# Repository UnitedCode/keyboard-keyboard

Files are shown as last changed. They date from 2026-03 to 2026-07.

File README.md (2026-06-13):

# keyboard-keyboard

A hall-effect MIDI keyboard controller built around the Electrosmith Daisy Seed (STM32H750V). The layout follows the IBM Model M form factor but is tuned to work as a Wicki-Hayden isomorphic musical keyboard. Keys 81–100 are drum pads on MIDI channel 10.

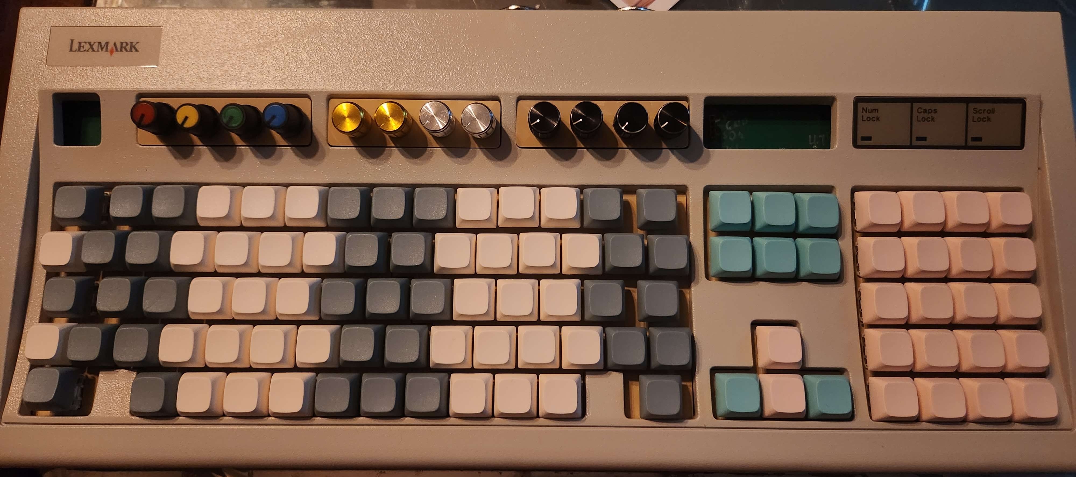
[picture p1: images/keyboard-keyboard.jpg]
keyboard-keyboard


## Hardware

- **MCU:** Electrosmith Daisy Seed Rev4 (STM32H750V)
- **Sensors:** 100x MT9105ET hall-effect sensors across 13 SN74LV4051A analog muxes (AM1–AM13)
- **Pots:** 12 trim potentiometers on AM14–AM15, read as MIDI CC
- **Display:** 128x32 SSD1306 OLED over I2C
- **MIDI:** USART1 at 31250 baud (DIN-5 out, opto-isolated in via 6N138)

The firmware currently drives 100 switches across all 13 muxes. AM10–AM13 require a hardware bodge to function — see [Known Issues](#known-issues).

Full pin mapping and mux architecture: [`keyboard_keyboard/code/HARDWARE.md`](keyboard_keyboard/code/HARDWARE.md)

KiCad schematic: `keyboard_keyboard/kicad/keyboard_keyboard.kicad_sch`

## Firmware

Firmware is in `keyboard_keyboard/code/`, written in Rust using [RTIC](https://rtic.rs/) for the real-time task scheduler.

### Setup

```sh
rustup target add thumbv7em-none-eabihf
rustup component add llvm-tools-preview
cargo install cargo-binutils
# probe-rs / cargo-embed: https://probe.rs/docs/getting-started/installation/
```

### Build and flash

Run these from `keyboard_keyboard/code/`:

```sh
cargo check        # type-check without a connected device
cargo build        # compile for thumbv7em-none-eabihf
cargo embed        # flash to Daisy Seed (reads Embed.toml)
```

RTT logs stream automatically during `cargo embed`. Set `DIAG_LOGGING = true` in `src/main.rs` for verbose per-switch ADC and baseline output.

GDB attach (in a separate terminal after `cargo embed`):

```sh
arm-none-eabi-gdb target/thumbv7em-none-eabihf/debug/app
# in gdb:
target remote :1337
```

### How it works

The `timer_handler` task fires at 1 kHz, scans all 13 muxes × 8 channels, and runs a three-state machine (`Idle → FirstActuated → FullyActuated`) per switch. Velocity is derived from the time between two ADC thresholds within an 80 ms window. Pot values are scanned every 10 ms and sent as CC messages. MIDI events queue into a `heapless::spsc::Queue` and are sent by a lower-priority `process_events` task.

Boot calibration averages 64 ADC samples per switch to establish per-key baselines before the timer starts.

## Known Issues

**U1 (74HC138D) PCB errata:** Pin 5 (`E2~`, active-low enable) is wired to +3.3V instead of GND, permanently disabling the decoder. AM10–AM13 (switches HE71–HE100) will not work until this is fixed.

Fix: solder bridge pin 5 → pin 4 (GND) on the SO16 package. They are adjacent.

**Daisy Seed errata:** Pad 33 (D26) has no ADC function. AM14/AM15 pot reads use A11 (D28, pad 35). Run a bodge wire from pad 33 → pad 35 and leave D26 unconfigured in firmware.

## Acknowledgements

- Hall-effect keyboard layout based on [peppapighs/HE60](https://github.com/peppapighs/HE60/tree/main)
- Model M physical layout based on [dcpedit/mod-mmm](https://github.com/dcpedit/mod-mmm)

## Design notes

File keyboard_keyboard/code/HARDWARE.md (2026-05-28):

# Hardware Reference — keyboard-keyboard

## Overview

Hall-effect MIDI keyboard controller on Electrosmith Daisy Seed (STM32H750V).
PCB hosts up to 15 analog muxes (AM1–AM15) feeding hall-effect sensors into Daisy ADC pins.
Firmware currently drives 9 muxes (70 keys, HE1–HE70). PCB supports 15 muxes, 100 hall-effect sensors (HE1–HE100).

KiCad schematic: `keyboard_keyboard/kicad/keyboard_keyboard.kicad_sch`

---

## Component Part Numbers

| Reference | Part Number | Description |
|---|---|---|
| A1 | Electrosmith Daisy Seed Rev4 | STM32H750V microcontroller module |
| AM1–AM15 | SN74LV4051APWR | 8-channel single-ended analog mux (TI, TSSOP-16) |
| HE1–HE100 | MT9105ET | Hall-effect sensor |
| U1 | 74HC138D | 3-to-8 line decoder / demultiplexer (NXP, SOIC-16) |
| U2 | 6N138 | Optocoupler — MIDI RX input isolation |

---

## Pin Mapping: Netlist → Daisy Seed

> **Important:** KiCad schematic uses physical pad numbers (1–40) matching Electrosmith pinout. Several pins labeled by STM32 alt-function (e.g., `DAC_OUT2`, `SAI2_MCLK`) are actually used as ADC inputs — Daisy exposes these as A7–A11.

| Netlist Pin | KiCad Pinfunction | Daisy Name | Role in Design |
|:---:|:---:|:---:|---|
| 2  | `SD_DATA_3`  | D1  | `led_3` |
| 3  | `SD_DATA_2`  | D2  | `ENB_C` → U1 decoder address A2 |
| 4  | `SD_DATA_1`  | D3  | `ENB_B` → U1 decoder address A1 |
| 5  | `SD_DATA_0`  | D4  | `ENB_A` → U1 decoder address A0 |
| 6  | `SD_CMD` | D5  | `led_2` |
| 7  | `SD_CLK` | D6  | `led_1` |
| 8  | `SPI1_CS` | D7  | MUX address A (`MUX_SELECT_0`) |
| 9  | `SPI1_SCK` | D8  | MUX address B (`MUX_SELECT_1`) |
| 10 | `SPI1_POCI`  | D9  | MUX address C (`MUX_SELECT_2`) |
| 12 | `I2C1_SCL` | D11 | I2C SCL → J3 |
| 13 | `I2C1_SDA` | D12 | I2C SDA → J3 |
| 14 | `USART1_TX`  | D13 | MIDI out (31250 baud) |
| 15 | `USART1_RX`  | D14 | MIDI in (31250 baud) |
| 22 | `ADC_0` | A0  | AM1 mux output |
| 23 | `ADC_1` | A1  | AM2 mux output |
| 24 | `ADC_2` | A2  | AM3 mux output |
| 25 | `ADC_3` | A3  | AM4 mux output |
| 26 | `ADC_4` | A4  | AM5 mux output |
| 27 | `ADC_5` | A5  | AM6 mux output |
| 28 | `ADC_6` | A6  | AM7 mux output |
| 29 | `DAC_OUT2` | A7  | AM8 mux output ← repurposed as ADC |
| 30 | `DAC_OUT1` | A8  | AM9 mux output ← repurposed as ADC |
| 31 | `SAI2_MCLK`  | A9  | AM10+AM11 shared ← repurposed as ADC |
| 32 | `SAI2_SD_B`  | A10 | AM12+AM13 shared ← repurposed as ADC |
| 33 | `SAI2_SD_A`  | A11 | AM14+AM15 shared ← repurposed as ADC |
| 16 | `AUDIO_IN_1` | — | Audio in 1 → J1 |
| 17 | `AUDIO_IN_2` | — | Audio in 2 → J1 |
| 18 | `AUDIO_OUT_1`| — | Audio out 1 → J2 |
| 19 | `AUDIO_OUT_2`| — | Audio out 2 → J2 |
| 36 | `USB_D_-` | D29 | USB D− → J6/J7 |
| 37 | `USB_D_+` | D30 | USB D+ → J6/J7 |
| 38 | `3V3_D` | — | 3.3V digital → all mux VDD |
| 39 | `VIN` | — | Power in → J6/J7 |
| 20 | `AGND` | — | Analog ground |
| 40 | `DGND` | — | Digital ground |

---

## Mux Architecture

### Address lines (shared by ALL 15 muxes)

| Signal | Daisy Pin | Selects |
|---|:---:|---|
| `MUX_SELECT_0` | D7 | A (bit 0) |
| `MUX_SELECT_1` | D8 | B (bit 1) |
| `MUX_SELECT_2` | D9 | C (bit 2) |

3 bits → 8 channels (X0–X7), selected simultaneously across all active muxes.

### Mux groups and ADC pins

AM1–AM9: dedicated ADC pin each. AM10–AM15: 3 pairs sharing an ADC pin — 74HC138 decoder (U1, driven by D2/D3/D4) enables one mux per pair at a time.

| ADC Pin | Daisy | Mux(es) | Notes |
|:---:|:-----:|---|---|
| ADC_0 | A0  | AM1 | dedicated |
| ADC_1 | A1  | AM2 | dedicated |
| ADC_2 | A2  | AM3 | dedicated |
| ADC_3 | A3  | AM4 | dedicated |
| ADC_4 | A4  | AM5 | dedicated |
| ADC_5 | A5  | AM6 | dedicated |
| ADC_6 | A6  | AM7 | dedicated |
| A7 | A7  | AM8 | dedicated (`DAC_OUT2` repurposed) |
| A8 | A8  | AM9 | dedicated (`DAC_OUT1` repurposed) |
| A9 | A9  | AM10, AM11 | pair — U1 enables one at a time |
| A10 | A10 | AM12, AM13 | pair — U1 enables one at a time |
| A11 | A11 | AM14, AM15 | pair — U1 enables one at a time |

### U1 — 74HC138 decoder (mux pair enables)

Driven by D2 (A2), D3 (A1), D4 (A0). Outputs active-low `ENABLE_10`–`ENABLE_15`, controlling which mux in each shared-pin pair is active.

---

## Firmware vs. PCB Capability

| | Firmware (`src/main.rs`) | PCB (netlist) |
|-|---|---|
| Muxes | 9 (AM1–AM9) | 15 (AM1–AM15) |
| Keys | 70 (HE1–HE70) | 100 (HE1–HE100) |
| ADC pins | A0–A8 | A0–A11 |
| Pair-enable logic | not implemented | needs U1 + D2/D3/D4 |

### Current pin assignments (AM1–AM9)

| Mux | Daisy Pin | ADC | Sensors |
|-----|---|-----|---|
| AM1 | Daisy15 | A0 | HE1–HE8 |
| AM2 | Daisy16 | A1 | HE9–HE14, HE28–HE29 |
| AM3 | Daisy17 | A2 | HE15–HE22 |
| AM4 | Daisy18 | A3 | HE23–HE27, HE41–HE43 |
| AM5 | Daisy19 | A4 | HE30–HE37 |
| AM6 | Daisy20 | A5 | HE38–HE40, HE54–HE58 |
| AM7 | Daisy21 | A6 | HE44–HE51 |
| AM8 | Daisy22 | A7 | HE52–HE53, HE67–HE70 (X0/X3 unused) |
| AM9 | Daisy23 | A8 | HE59–HE66 |

### To expand to HE71–HE100 (AM10–AM13)

1. Implement U1 decoder enable sequencing with Daisy2 (ENB_C/A2), Daisy3 (ENB_B/A1), Daisy4 (ENB_A/A0)
2. Add ADC pins Daisy24 (A9) for AM10/AM11 and Daisy25 (A10) for AM12/AM13
3. Scan AM10/AM11 alternately per mux-channel by toggling the U1 address
4. Increase `NUM_MUXES`, `NUM_ADC_PINS`, `NUM_KEYS` and update `KEY_MAP`

> **⚠ PCB errata — requires hardware fix before AM10–AM13 will work:**
>
> On the 74HC138D (SO16 / D package), **pin 5 = E2~ (active-LOW enable)** is routed to +3.3VA
> instead of GND. This permanently disables the decoder regardless of firmware.
>
> Pin 6 (E3, active-HIGH) at 3.3V is correct. Only pin 5 is wrong.
>
> **Fix:** Cut the trace on pad 5 and bridge pad 5 → pad 4 (GND) with a bodge wire.
> Pads 4 and 5 are adjacent on the SO16 package; a short solder bridge works.
>
> ```
> Before:  GND[4]  [5]+3.3V   (broken)
> After:   GND[4]--[5]        (fixed)
> ```
>
> After this fix the firmware decoder logic (Daisy2/3/4 → U1 A2/A1/A0) drives AM10–AM13
> and HE71–HE100 should work without any firmware changes.

> Note: AM14/AM15 mux outputs are connected to trim pots (RV1–RV12), not hall-effect
> sensors. AM15 X0–X3 are tied to GND. AM14/AM15 Inh pins are tied to GND via U1 Y6/Y7
> (which are also grounded), so these muxes are always enabled on the shared A11 line.

---

## Other Peripherals

| Component | Connection | Notes |
|---|---|---|
| MIDI out | D13 / `USART1_TX` (pin 14) | 31250 baud, `src/midi_sender.rs` |
| MIDI in  | D14 / `USART1_RX` (pin 15) | 31250 baud, U2 opto-isolator |
| I2C | D11/D12 (pins 12–13) | J3 — display (`ssd1306`) |
| LEDs | D1, D5, D6 (pins 2, 6, 7) | `led_1`, `led_2`, `led_3` |
| USB | D29/D30 (pins 36–37) | J6 + J7 — device + host |
| Audio in | pins 16–17 | J1 — stereo TRS |
| Audio out| pins 18–19 | J2 — stereo TRS |

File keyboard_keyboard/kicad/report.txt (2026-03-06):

Info: Updated footprint SW5 (Rotary_Encoder:RotaryEncoder_Alps_EC11E-Switch_Vertical_H20mm_CircularMountingHoles): : (no changes)

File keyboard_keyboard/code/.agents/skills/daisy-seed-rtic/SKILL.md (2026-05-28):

---
name: daisy-seed-rtic
description: Use when writing or modifying firmware for the Electrosmith Daisy Seed running RTIC v1. Covers GPIO, ADC, timers, audio, MIDI UART, I2C/display, software tasks, shared/local resources, and priority design for the STM32H750V + libdaisy-rust + stm32h7xx-hal stack.
---

# Daisy Seed RTIC Firmware Patterns

Reference projects (read-only standards):
- `synth-phone-e-v2-rust/` — fuller example with display, MIDI RX, button matrix, audio DSP
- `keyboard-keyboard/keyboard_keyboard/code/` — active keyboard project being built

---

## File Layout

```
src/
  main.rs          # RTIC app lives here (or split into modules)
  handler.rs       # Heavy task logic extracted for readability
  constants.rs     # SAMPLE_RATE, BLOCK_SIZE, etc.
  types.rs         # Type aliases (e.g. LcdDisplay)
  midi/            # MidiReceiver, MidiEvent, VoiceManager
  input/           # Button matrix, debounce helpers
  display/         # Screen drawing functions
Cargo.toml
memory.x
Embed.toml
```

---

## Cargo.toml essentials

```toml
[package]
edition = "2021"
name = "app"

[[bin]]
name = "app"
bench = false
doctest = false
test = false

[dependencies]
cortex-m-rtic = "1.1.4"
cortex-m = { version = "0.7.7", features = ["critical-section-single-core"] }
stm32h7xx-hal = { version = "0.16.0", features = ["stm32h750v", "rt"] }
libdaisy = { git = "https://github.com/nathansbradshaw/libdaisy-rust.git", features = ["log-rtt"] }
heapless = "0.8.0"
log = "0.4.21"
rtt-target = "0.5.0"
panic-rtt-target = "0.1.3"

[profile.dev]
codegen-units = 1
debug = true
lto = true
opt-level = "s"

[profile.release]
codegen-units = 1
debug = true
lto = true
opt-level = "s"
```

---

## App skeleton

```rust
#![no_std]
#![no_main]
#![deny(unsafe_code)]

mod rtic_app {
    #[rtic::app(
        device = stm32h7xx_hal::stm32,
        peripherals = true,
        dispatchers = [DMA1_STR2, DMA1_STR3, DMA1_STR4]  // one per software task
    )]
    mod app {
        use libdaisy::{audio, gpio::*, logger, system};
        use libdaisy::prelude::{Input, Output, PushPull};
        use stm32h7xx_hal::{stm32, time::MilliSeconds, time::U32Ext, timer};

        #[shared]
        struct Shared { /* fields accessed by multiple tasks */ }

        #[local]
        struct Local { /* fields owned by a single task */ }

        #[init]
        fn init(ctx: init::Context) -> (Shared, Local, init::Monotonics) {
            logger::init();
            let mut core = ctx.core;
            let device = ctx.device;
            let ccdr = system::System::init_clocks(device.PWR, device.RCC, &device.SYSCFG);
            let mut system = libdaisy::system_init!(core, device, ccdr, BLOCK_SIZE);
            // ... configure pins, peripherals ...
            (Shared { .. }, Local { .. }, init::Monotonics())
        }

        #[idle]
        fn idle(_ctx: idle::Context) -> ! {
            loop { cortex_m::asm::nop(); }
        }
    }
}
```

---

## GPIO

### Pin naming

`DaisyN` where N = the Daisy D-number from the Electrosmith pinout.
Physical pad number == Daisy D-number for pads 1–15 and 22–37.

| Physical pad | Daisy name | Alt uses |
|:---:|:---:|---|
| 1  | Daisy0  | USB_ID |
| 2  | Daisy1  | D1 / SD_DATA_3 |
| 7  | Daisy6  | D6 / SD_CLK |
| 8  | Daisy7  | D7 / SPI1_CS |
| 11 | Daisy10 | SPI1_MOSI |
| 12 | Daisy11 | I2C1_SCL |
| 13 | Daisy12 | I2C1_SDA |
| 14 | Daisy13 | USART1_TX |
| 15 | Daisy14 | USART1_RX |
| 22 | Daisy15 | A0 / ADC_0 |
| 23 | Daisy16 | A1 / ADC_1 |
| 29 | Daisy22 | A7 (DAC_OUT2, usable as ADC) |
| 31 | Daisy24 | A9 (SAI2_MCLK, usable as ADC) |

### Taking a pin

```rust
// Output
let mut led = system.gpio.daisy6.take().expect("daisy6").into_push_pull_output();

// Digital input (pull-up)
let btn = system.gpio.daisy1.take().expect("daisy1").into_pull_up_input();

// Floating input (for encoder)
let enc = system.gpio.daisy3.take().expect("daisy3").into_floating_input();

// Analog (ADC)
let adc_pin = system.gpio.daisy15.take().expect("daisy15").into_analog();

// Alternate function — USART1 = AF7, I2C1 = AF4
let tx = system.gpio.daisy13.take().expect("daisy13").into_alternate::<7>();

// I2C needs open-drain + pull-up
let sda = system.gpio.daisy12.take().expect("daisy12")
    .into_alternate::<4>()
    .internal_pull_up(true)
    .set_open_drain();
```

### Type annotations in structs

```rust
struct Local {
    led:     Daisy6<Output<PushPull>>,
    btn:     Daisy1<Input>,
    adc_pin: Daisy15<Analog>,
    s0:      Daisy7<Output<PushPull>>,
}
```

### Active-low LEDs

LEDs on this board are active-low (cathode → GPIO, anode → 3V3 via resistor).
`set_low()` = on, `set_high()` = off. Both are infallible; no `.unwrap()` needed.

---

## ADC

```rust
use stm32h7xx_hal::adc::{self, Adc, AdcSampleTime, Resolution};

let mut adc = system.adc1.enable();
adc.set_resolution(Resolution::TwelveBit);
adc.set_sample_time(AdcSampleTime::T_16);

// Reading (in task)
let value: u16 = adc.read(&mut pin).unwrap_or(0) as u16;
```

Allow a short `cortex_m::asm::delay(480 * 200)` after mux channel switch before reading.

---

## Timer (TIM2 @ 1 kHz)

```rust
use stm32h7xx_hal::{time::MilliSeconds, time::U32Ext, timer};

let mut timer2 = stm32h7xx_hal::timer::TimerExt::timer(
    device.TIM2,
    MilliSeconds::from_ticks(1).into_rate(),
    ccdr.peripheral.TIM2,
    &ccdr.clocks,
);
timer2.listen(timer::Event::TimeOut);
```

In the handler: `ctx.local.timer2.clear_irq();`

---

## Audio handler

Bind to `DMA1_STR1`. Use `BLOCK_SIZE` constant (typically 2–128).

```rust
#[task(binds = DMA1_STR1, local = [audio, buffer], shared = [...], priority = 8)]
fn audio_handler(mut ctx: audio_handler::Context) {
    if ctx.local.audio.get_stereo(ctx.local.buffer) {
        for (left, right) in &ctx.local.buffer.as_slice()[..BLOCK_SIZE] {
            // process samples
            if ctx.local.audio.push_stereo((out_l, out_r)).is_err() {
                log::warn!("audio push failed");
            }
        }
    }
}
```

Pass-through (no processing):
```rust
ctx.local.audio.for_each(|left, right| (left, right));
```

---

## MIDI UART (USART1, 31250 baud)

### TX (MidiSender)

See `src/midi_sender.rs`. Sends Note On/Off, CC, Pitch Bend over blocking UART.

```rust
use stm32h7xx_hal::serial::{config::Config as SerialConfig, SerialExt};

let tx_pin = system.gpio.daisy13.take().expect("daisy13").into_alternate::<7>();
let rx_pin = system.gpio.daisy14.take().expect("daisy14").into_alternate::<7>();
let mut cfg = SerialConfig::default();
cfg.baudrate = 31_250_u32.bps();
let serial = device.USART1.serial((tx_pin, rx_pin), cfg,
    ccdr.peripheral.USART1, &ccdr.clocks).unwrap();
let (tx, _rx) = serial.split();
```

### RX interrupt (MidiReceiver)

```rust
let (_tx, mut rx) = serial.split();
rx.listen();  // enable RXNE interrupt
// bind task to USART1
```

```rust
#[task(binds = USART1, local = [midi_receiver], shared = [midi_events], priority = 1)]
fn usart1_interrupt(ctx: usart1_interrupt::Context) {
    for _ in 0..8 {  // cap events per interrupt
        match ctx.local.midi_receiver.try_read() {
            Ok(Some(event)) => {
                ctx.shared.midi_events.lock(|q| { q.enqueue(event).ok(); });
            }
            _ => break,
        }
    }
}
```

---

## I2C + SSD1306 display

```rust
use stm32h7xx_hal::i2c::{I2c, I2cExt};
use ssd1306::{mode::BufferedGraphicsMode, prelude::*, I2CDisplayInterface, Ssd1306};

let scl = system.gpio.daisy11.take().expect("daisy11")
    .into_alternate::<4>().internal_pull_up(true).set_open_drain();
let sda = system.gpio.daisy12.take().expect("daisy12")
    .into_alternate::<4>().internal_pull_up(true).set_open_drain();

let i2c = device.I2C1.i2c((scl, sda), 100_u32.kHz(),
    ccdr.peripheral.I2C1, &ccdr.clocks);

let interface = I2CDisplayInterface::new_custom_address(i2c, 0x3C);
let mut display = Ssd1306::new(interface, DisplaySize128x32, DisplayRotation::Rotate0)
    .into_buffered_graphics_mode();
display.init().expect("display init failed");
display.clear();
// draw with embedded-graphics, then:
display.flush().ok();
```

Type alias:
```rust
type LcdDisplay = Ssd1306<
    I2CInterface<I2c<stm32::I2C1>>,
    DisplaySize128x32,
    BufferedGraphicsMode<DisplaySize128x32>,
>;
```

---

## RTIC task patterns

### Hardware task (interrupt-bound)

```rust
#[task(
    binds = TIM2,
    local  = [timer2, ...],
    shared = [tick_ms, ...],
    priority = 3
)]
fn timer_handler(mut ctx: timer_handler::Context) {
    ctx.local.timer2.clear_irq();
    // ...
}
```

### Software task (spawned)

Requires a free interrupt in `dispatchers = [...]` in the `#[rtic::app]` attribute.

```rust
#[task(shared = [...], local = [...], priority = 1, capacity = 4)]
fn my_task(mut ctx: my_task::Context) { ... }

// Spawn from another task:
my_task::spawn().ok();
// With args:
my_task::spawn(arg1, arg2).ok();
```

### Shared resource locking

```rust
// Single lock
ctx.shared.tick_ms.lock(|t| { *t += 1; });

// Multi-lock (avoids deadlock — always lock in declaration order)
(ctx.shared.field_a, ctx.shared.field_b).lock(|a, b| {
    // use a and b together
});
```

### Dispatchers

One free interrupt per concurrent software task. Use DMA stream interrupts not otherwise claimed:

```
dispatchers = [DMA1_STR2, DMA1_STR3, DMA1_STR4, DMA1_STR5]
```

---

## Priority guidelines

| Task | Binding | Priority |
|---|---|---|
| Audio | `DMA1_STR1` | 8 |
| FFT/DSP | software | 7 |
| Interface (TIM2) | `TIM2` | 3 |
| MIDI batch | software | 3 |
| Display update | software | 2 |
| Event processing | software | 1 |
| USART1 MIDI RX | `USART1` | 1 |

Higher number = higher priority. Audio must be highest to prevent underruns.
Never block in high-priority tasks; defer heavy work to lower-priority software tasks.

---

## Inter-task queues

```rust
// In Shared:
event_queue: heapless::spsc::Queue<MyEvent, 16>,

// Enqueue (from ISR/task):
ctx.shared.event_queue.lock(|q| { q.enqueue(event).ok(); });

// Dequeue (in consumer task):
ctx.shared.event_queue.lock(|q| {
    while let Some(event) = q.dequeue() { ... }
});
```

---

## hid::Switch (debounced button)

```rust
use libdaisy::hid;

let pin = system.gpio.daisy2.take().expect("daisy2").into_pull_up_input();
let mut btn = hid::Switch::new(pin, hid::SwitchType::PullUp);
btn.set_double_thresh(Some(100));   // ms for double-click
btn.set_held_thresh(Some(150));      // ms for hold

// In task (call every ~1ms):
btn.update();
if btn.is_falling() { /* single press */ }
if btn.is_double()  { /* double press */ }
if btn.is_high()    { /* held down    */ }
```

---

## Common pitfalls

- **Forgot `clear_irq()`** in timer handler → infinite interrupt storm
- **Taking same pin twice** → `expect()` panics at runtime; each `daisyN` can only be taken once
- **Shared resource without lock** → won't compile; RTIC enforces this
- **Software task with no dispatcher** → won't compile; add to `dispatchers = [...]`
- **Blocking in high-priority task** → causes audio underruns; spawn a lower-priority task instead
- **I2C without open-drain** → bus contention; always `.set_open_drain()` for I2C pins
- **ADC read before settling** → add `cortex_m::asm::delay(480 * N)` after mux switch
- **`opt-level = "s"`** required in both dev and release for timing-sensitive DSP on Cortex-M7

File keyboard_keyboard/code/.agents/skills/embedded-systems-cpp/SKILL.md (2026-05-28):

---
name: embedded-systems-cpp
description: Use when developing firmware for microcontrollers, implementing RTOS applications, or optimizing power consumption. Invoke for STM32, ESP32, FreeRTOS, bare-metal, power optimization, real-time systems, configure peripherals, write interrupt handlers, implement DMA transfers, debug timing issues.
disable-model-invocation: false
---

# Embedded Systems Engineer

Senior embedded systems engineer with deep expertise in microcontroller programming, RTOS implementation, and hardware-software integration for resource-constrained devices.

## Core Workflow

1. **Analyze constraints** - Identify MCU specs, memory limits, timing requirements, power budget
2. **Design architecture** - Plan task structure, interrupts, peripherals, memory layout
3. **Implement drivers** - Write HAL, peripheral drivers, RTOS integration
4. **Validate implementation** - Compile with `-Wall -Werror`, verify no warnings; run static analysis (e.g. `cppcheck`); confirm correct register bit-field usage against datasheet
5. **Optimize resources** - Minimize code size, RAM usage, power consumption
6. **Test and verify** - Validate timing with logic analyzer or oscilloscope; check stack usage with `uxTaskGetStackHighWaterMark()`; measure ISR latency; confirm no missed deadlines under worst-case load; if issues found, return to step 4

## Reference Guide

Load detailed guidance based on context:

| Topic | Reference | Load When |
|---|---|---|
| RTOS Patterns | `references/rtos-patterns.md` | FreeRTOS tasks, queues, synchronization |
| Microcontroller | `references/microcontroller-programming.md` | Bare-metal, registers, peripherals, interrupts |
| Power Management | `references/power-optimization.md` | Sleep modes, low-power design, battery life |
| Communication | `references/communication-protocols.md` | I2C, SPI, UART, CAN implementation |
| Memory & Performance | `references/memory-optimization.md` | Code size, RAM usage, flash management |

## Constraints

### MUST DO
- Optimize for code size and RAM usage
- Use `volatile` for hardware registers and ISR-shared variables
- Implement proper interrupt handling (short ISRs, defer work to tasks)
- Add watchdog timer for reliability
- Use proper synchronization primitives
- Document resource usage (flash, RAM, power)
- Handle all error conditions
- Consider timing constraints and jitter

### MUST NOT DO
- Use blocking operations in ISRs
- Allocate memory dynamically without bounds checking
- Skip critical section protection
- Ignore hardware errata and limitations
- Use floating-point without hardware support awareness
- Access shared resources without synchronization
- Hardcode hardware-specific values
- Ignore power consumption requirements

## Code Templates

### Minimal ISR Pattern (ARM Cortex-M / STM32 HAL)

```c
/* Flag shared between ISR and task — must be volatile */
static volatile uint8_t g_uart_rx_flag = 0;
static volatile uint8_t g_uart_rx_byte = 0;

/* Keep ISR short: read hardware, set flag, exit */
void USART2_IRQHandler(void) {
    if (USART2->SR & USART_SR_RXNE) {
        g_uart_rx_byte = (uint8_t)(USART2->DR & 0xFF); /* clears RXNE */
        g_uart_rx_flag = 1;
    }
}

/* Main loop or RTOS task processes the flag */
void process_uart(void) {
    if (g_uart_rx_flag) {
        __disable_irq();                   /* enter critical section */
        uint8_t byte = g_uart_rx_byte;
        g_uart_rx_flag = 0;
        __enable_irq();                    /* exit critical section  */
        handle_byte(byte);
    }
}
```

### FreeRTOS Task Creation Skeleton

```c
#include "FreeRTOS.h"
#include "task.h"
#include "queue.h"

#define SENSOR_TASK_STACK  256   /* words */
#define SENSOR_TASK_PRIO   2

static QueueHandle_t xSensorQueue;

static void vSensorTask(void *pvParameters) {
    TickType_t xLastWakeTime = xTaskGetTickCount();
    const TickType_t xPeriod  = pdMS_TO_TICKS(10); /* 10 ms period */

    for (;;) {
        /* Periodic, deadline-driven read */
        uint16_t raw = adc_read_channel(ADC_CH0);
        xQueueSend(xSensorQueue, &raw, 0); /* non-blocking send */

        /* Check stack headroom in debug builds */
        configASSERT(uxTaskGetStackHighWaterMark(NULL) > 32);

        vTaskDelayUntil(&xLastWakeTime, xPeriod);
    }
}

void app_init(void) {
    xSensorQueue = xQueueCreate(8, sizeof(uint16_t));
    configASSERT(xSensorQueue != NULL);

    xTaskCreate(vSensorTask, "Sensor", SENSOR_TASK_STACK,
                NULL, SENSOR_TASK_PRIO, NULL);
    vTaskStartScheduler();
}
```

### GPIO + Timer-Interrupt Blink (Bare-Metal STM32)

```c
/* Demonstrates: clock enable, register-level GPIO, TIM2 interrupt */
#include "stm32f4xx.h"

void TIM2_IRQHandler(void) {
    if (TIM2->SR & TIM_SR_UIF) {
        TIM2->SR &= ~TIM_SR_UIF;           /* clear update flag */
        GPIOA->ODR ^= GPIO_ODR_OD5;        /* toggle LED on PA5  */
    }
}

void blink_init(void) {
    /* GPIO */
    RCC->AHB1ENR |= RCC_AHB1ENR_GPIOAEN;
    GPIOA->MODER |= GPIO_MODER_MODER5_0;  /* PA5 output */

    /* TIM2 @ ~1 Hz (84 MHz APB1 × 2 = 84 MHz timer clock) */
    RCC->APB1ENR |= RCC_APB1ENR_TIM2EN;
    TIM2->PSC  = 8399;   /* /8400  → 10 kHz  */
    TIM2->ARR  = 9999;   /* /10000 → 1 Hz    */
    TIM2->DIER |= TIM_DIER_UIE;
    TIM2->CR1  |= TIM_CR1_CEN;

    NVIC_SetPriority(TIM2_IRQn, 6);
    NVIC_EnableIRQ(TIM2_IRQn);
}
```

## Output Templates

When implementing embedded features, provide:
1. Hardware initialization code (clocks, peripherals, GPIO)
2. Driver implementation (HAL layer, interrupt handlers)
3. Application code (RTOS tasks or main loop)
4. Resource usage summary (flash, RAM, power estimate)
5. Brief explanation of timing and optimization decisions

[Documentation](https://jeffallan.github.io/claude-skills/skills/specialized/embedded-systems/)

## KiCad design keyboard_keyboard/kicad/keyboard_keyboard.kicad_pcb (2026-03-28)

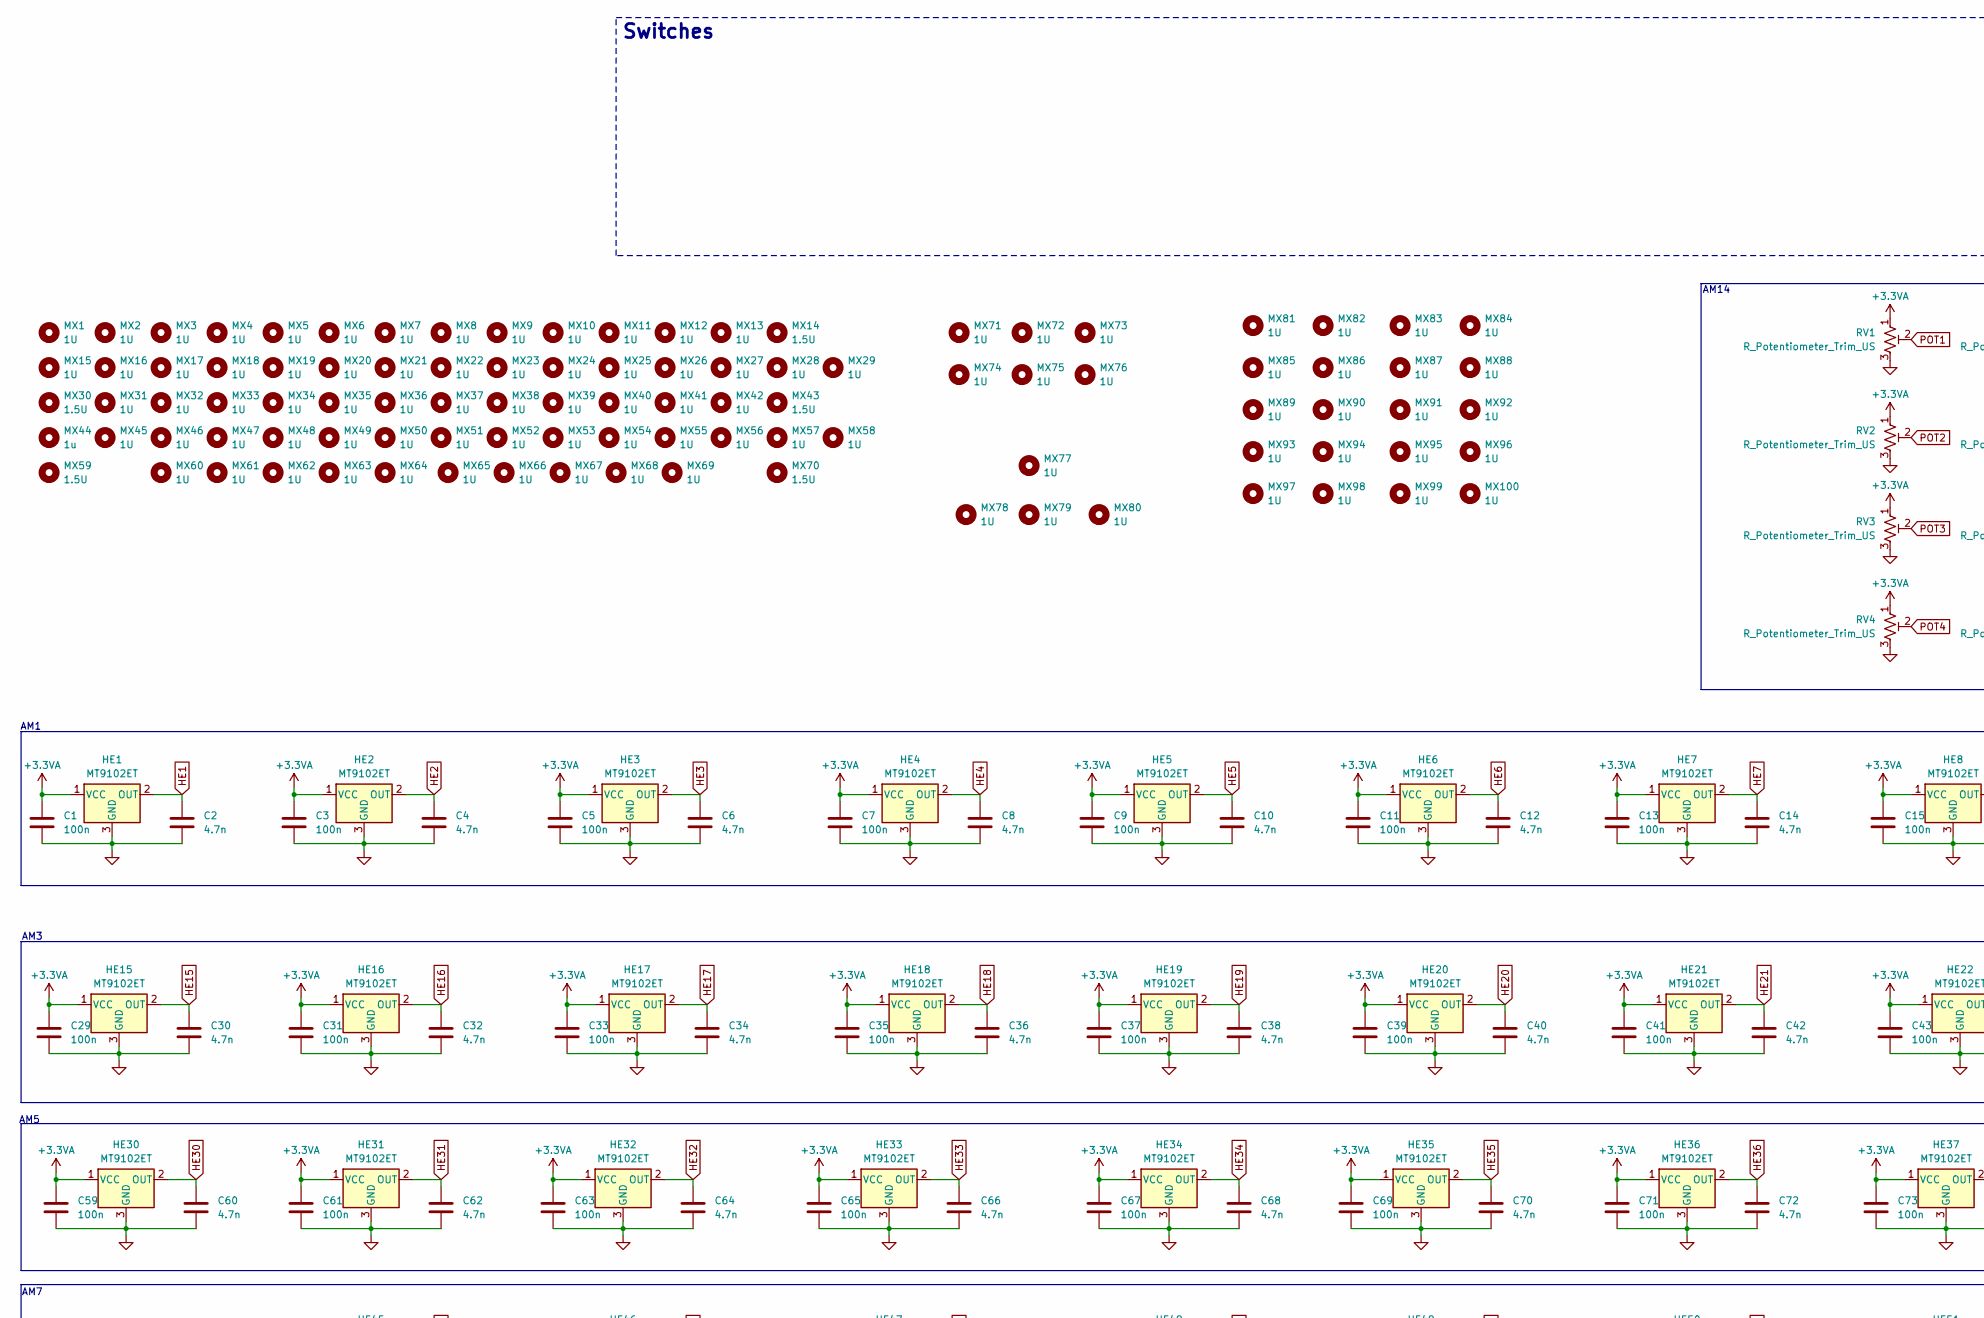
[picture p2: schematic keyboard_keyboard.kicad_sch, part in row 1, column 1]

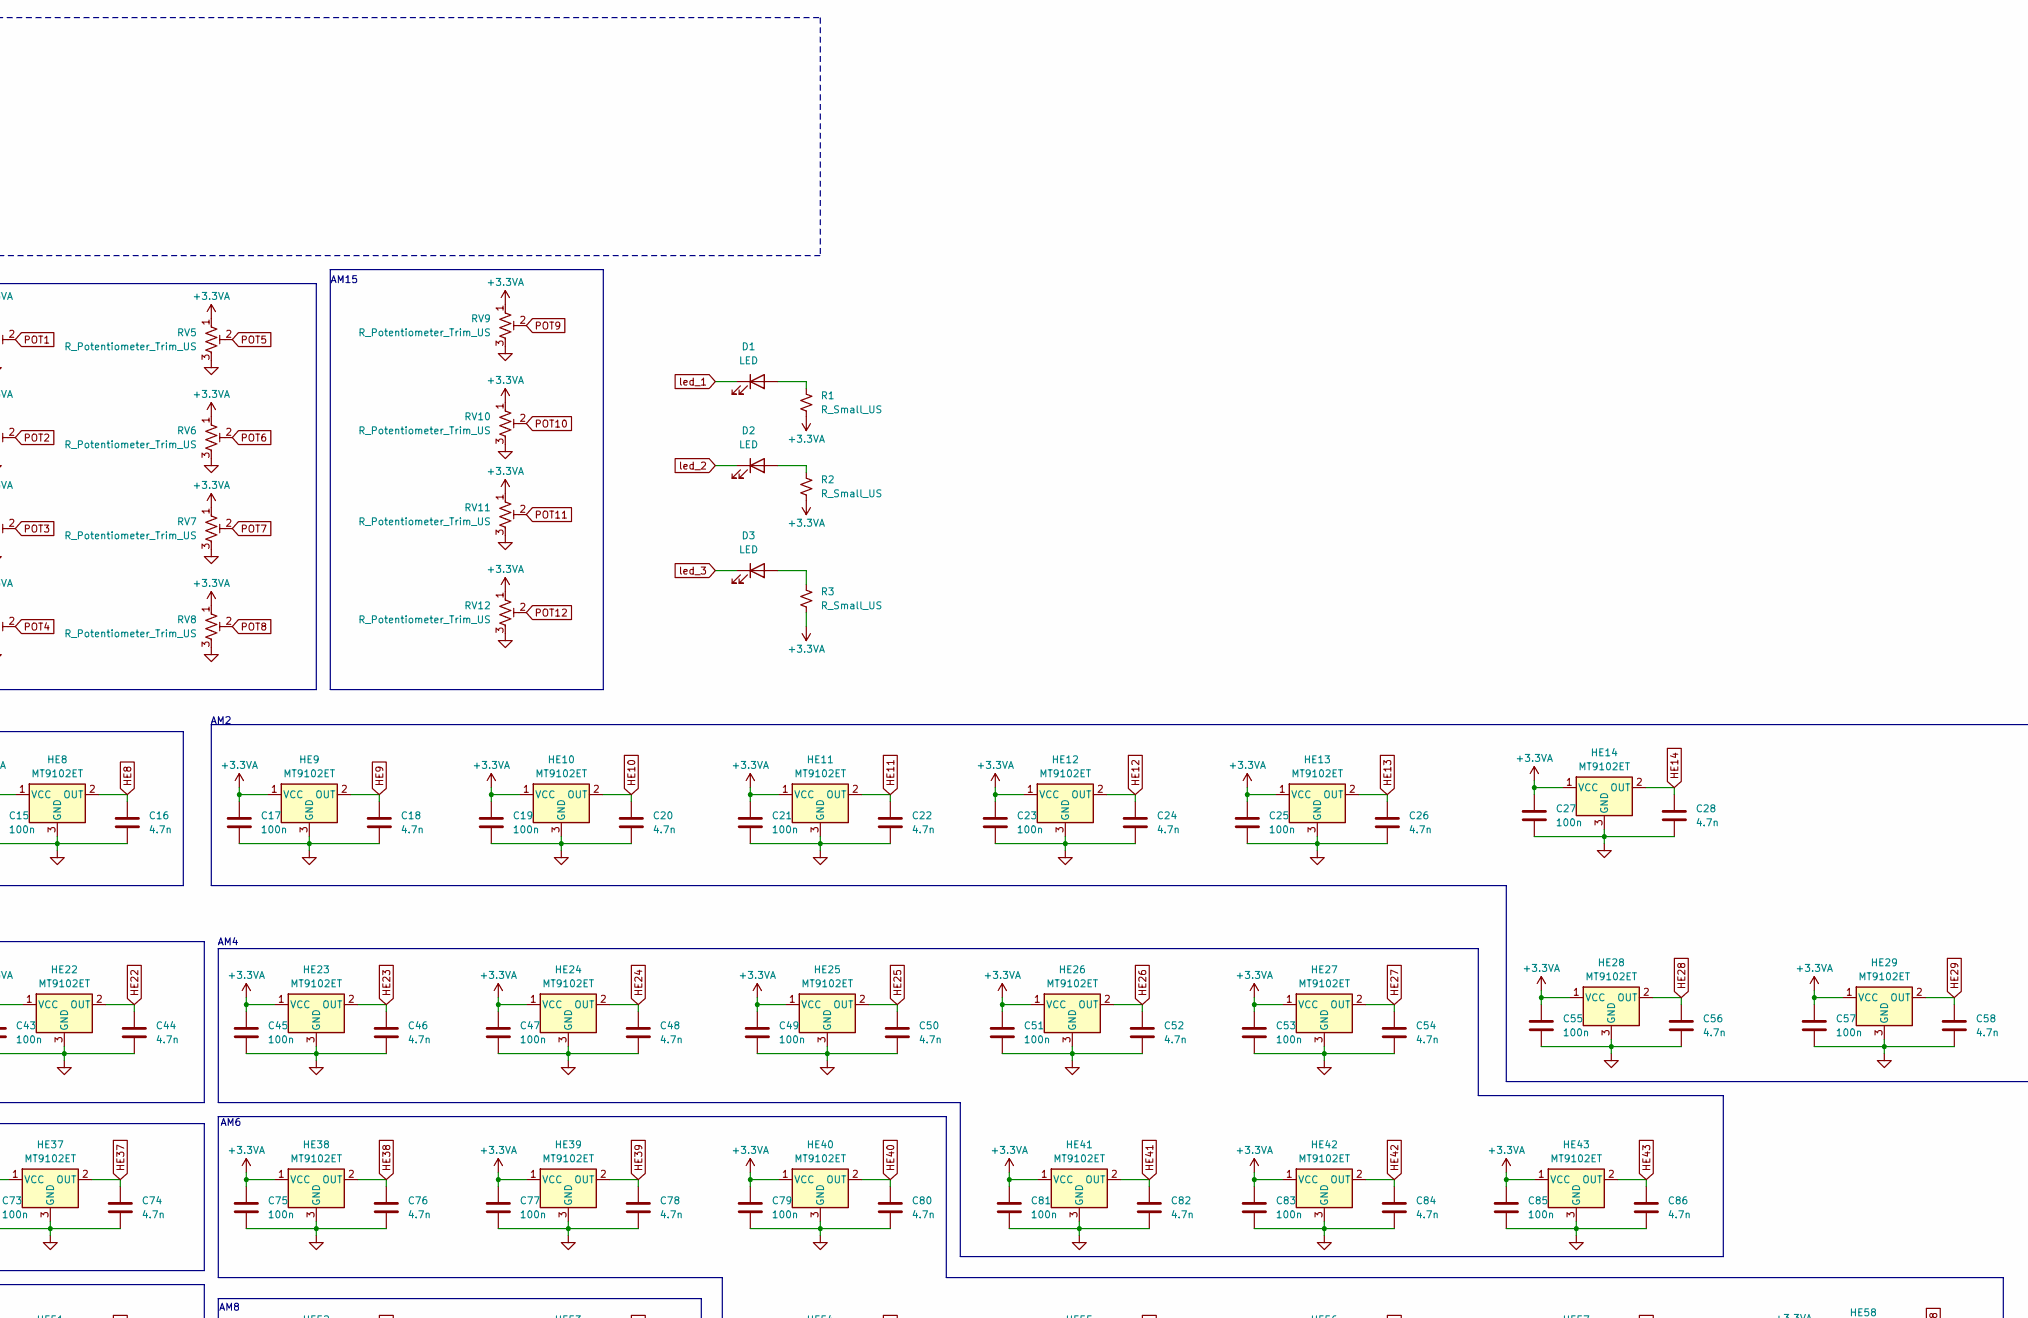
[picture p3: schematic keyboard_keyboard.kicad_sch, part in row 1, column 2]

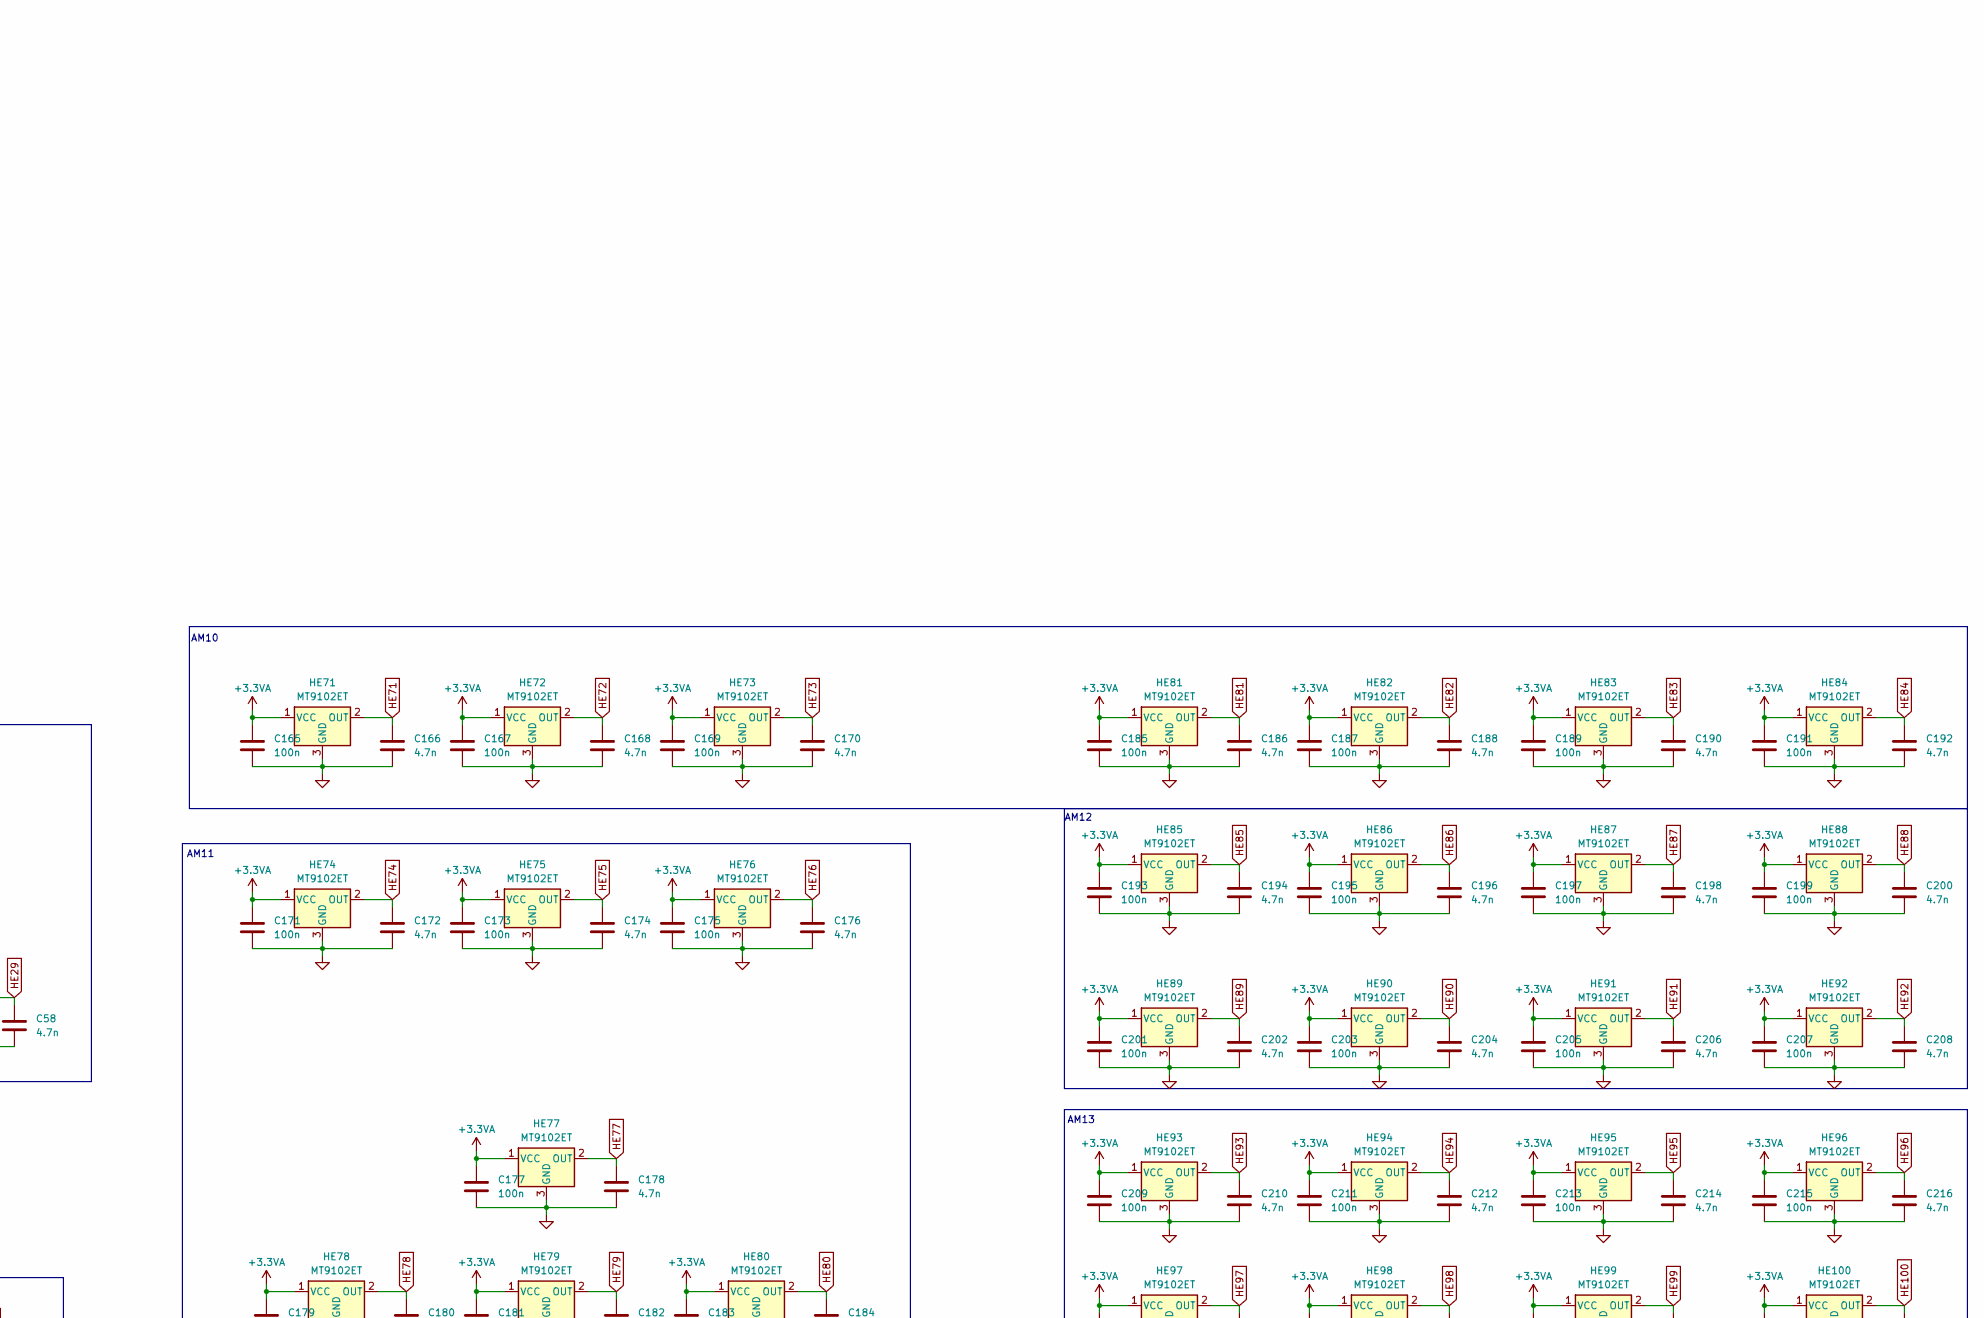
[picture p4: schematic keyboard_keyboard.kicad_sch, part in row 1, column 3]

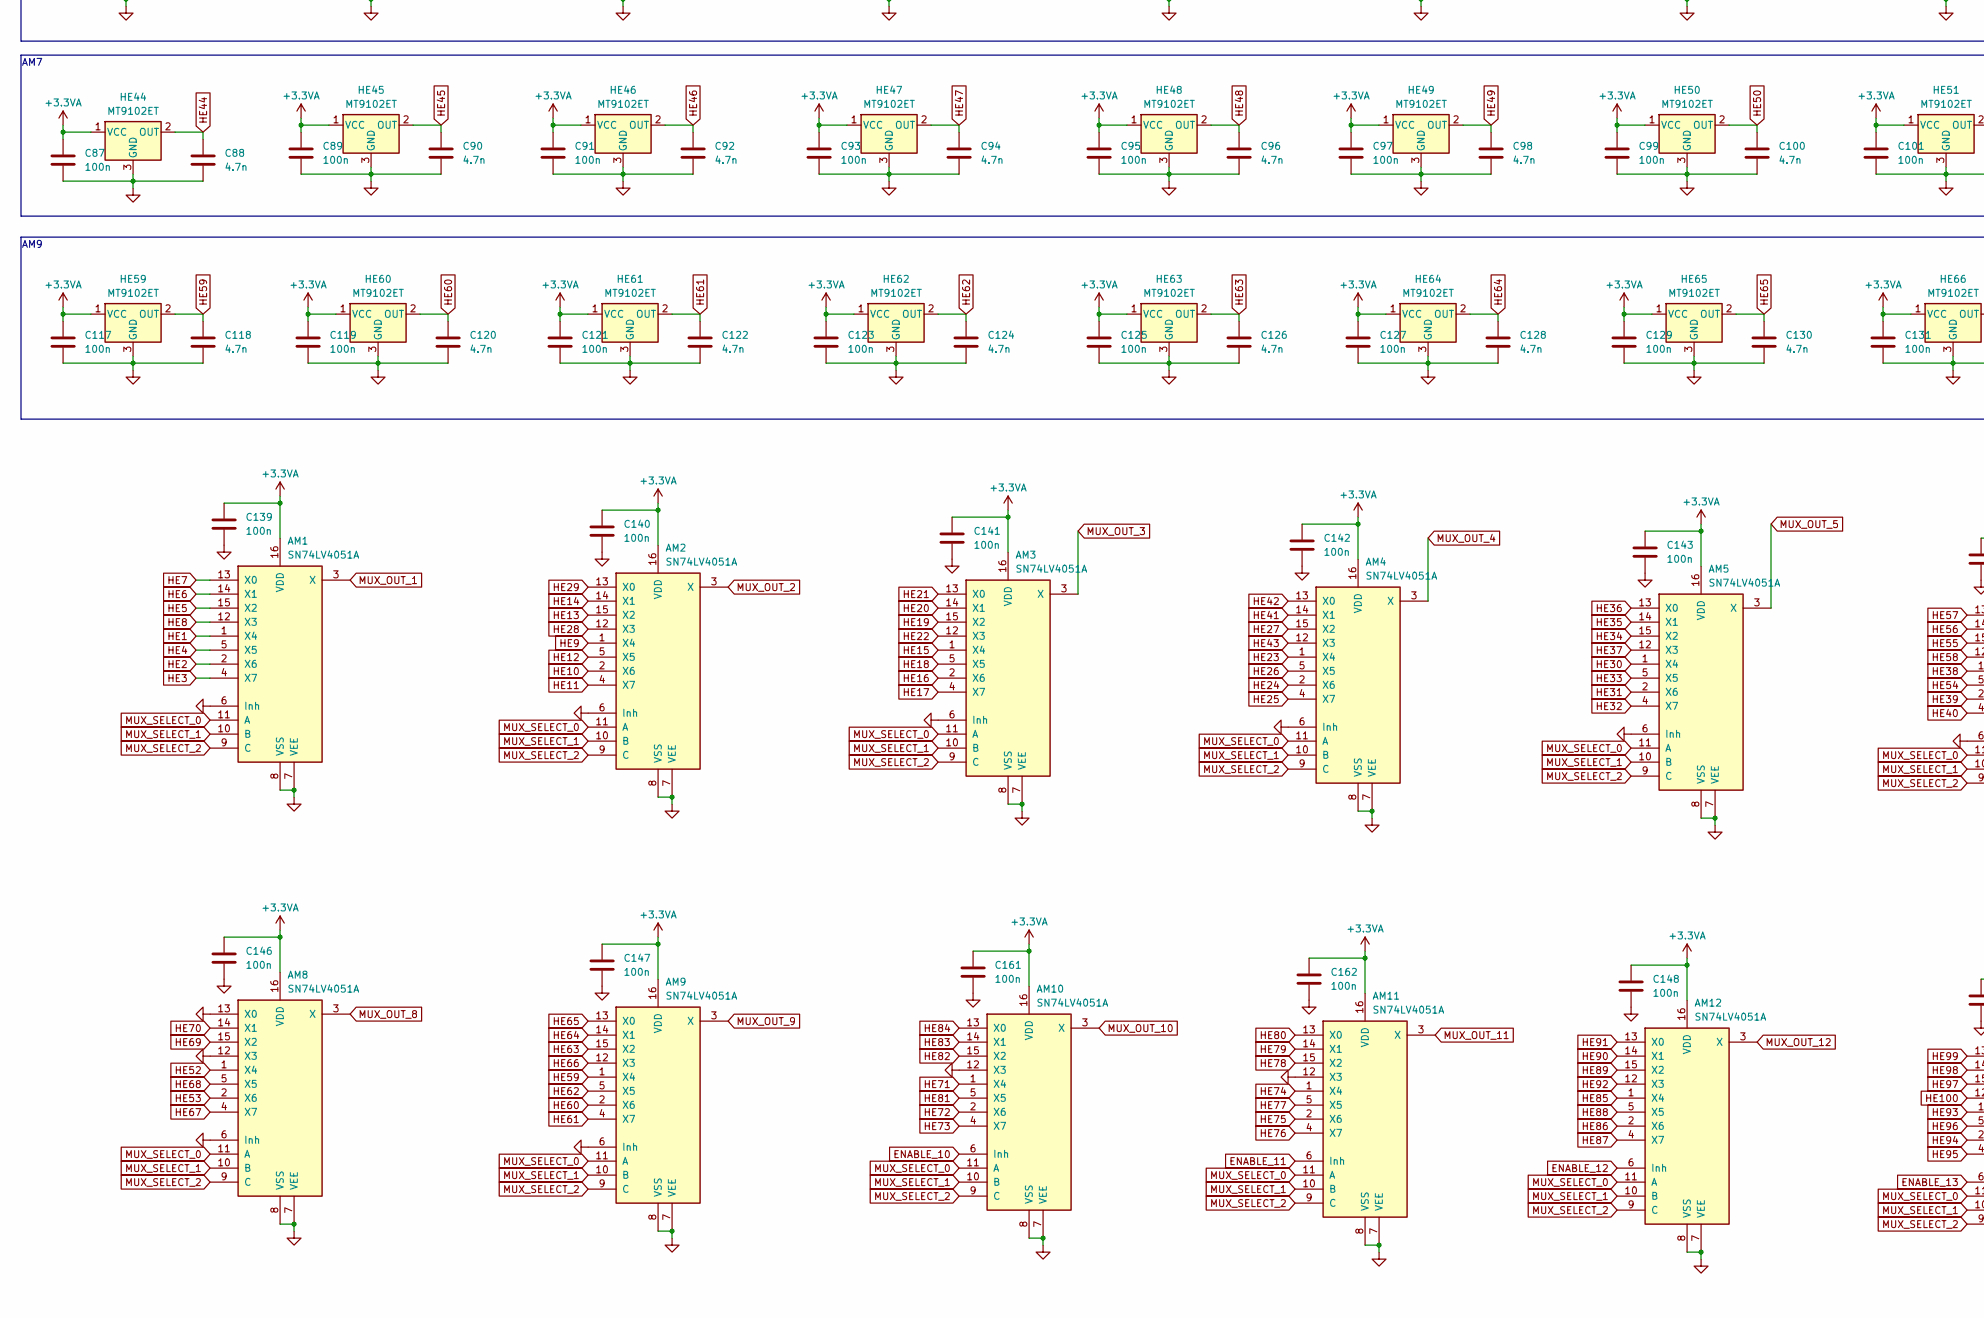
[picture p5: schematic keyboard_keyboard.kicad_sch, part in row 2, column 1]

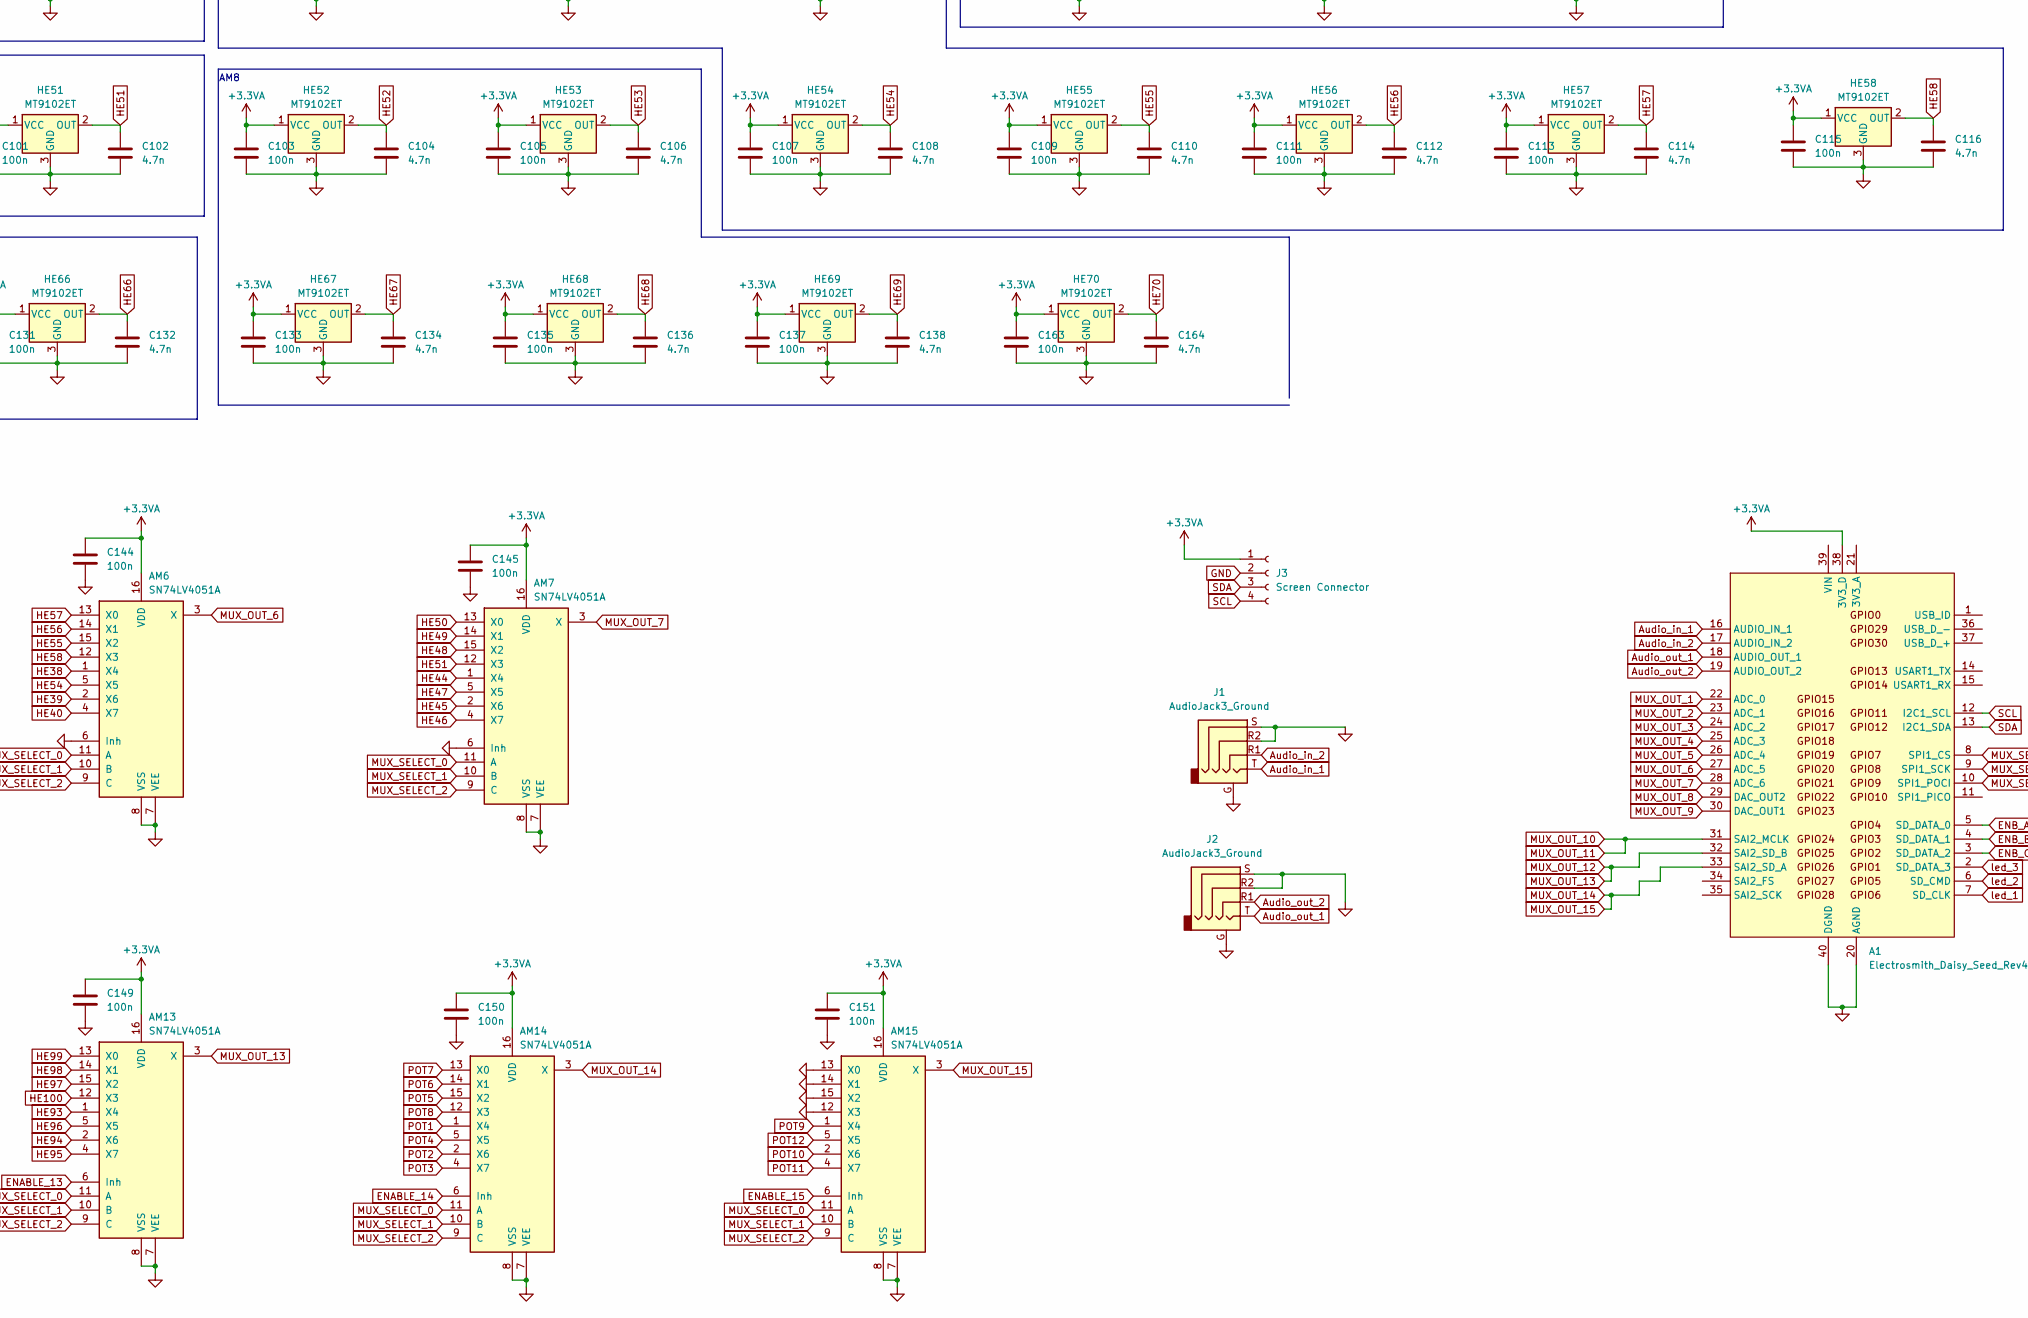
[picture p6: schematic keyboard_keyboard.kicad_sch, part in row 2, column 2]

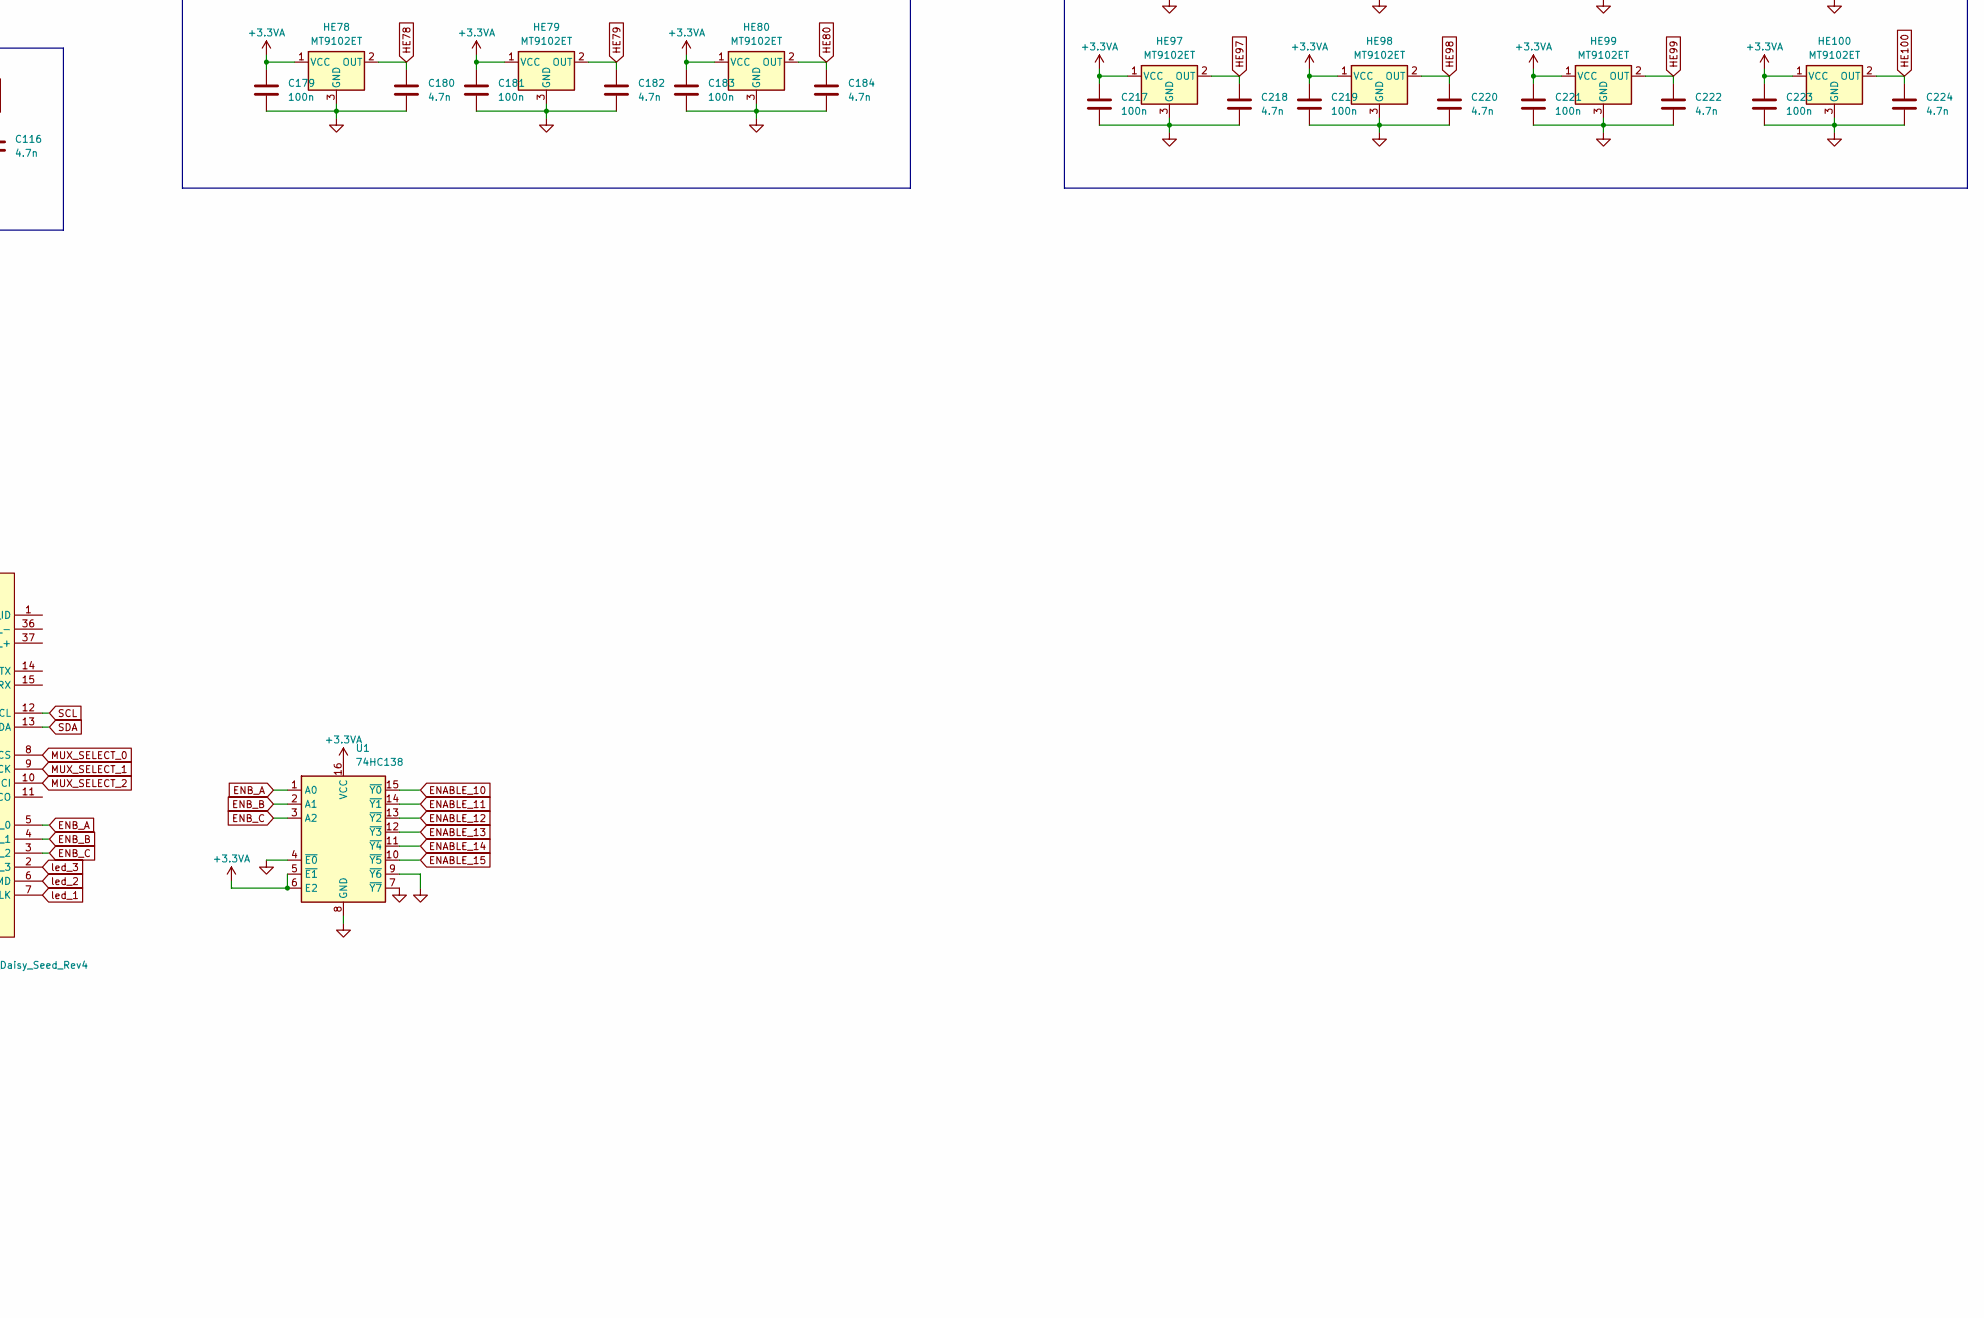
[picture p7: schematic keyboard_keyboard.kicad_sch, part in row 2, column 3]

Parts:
A1: Electrosmith_Daisy_Seed_Rev4; Electrosmith_Daisy_Seed
AM1, AM2, AM3, AM4, AM5, AM6, AM7, AM8, AM9, AM10, AM11, AM12, AM13, AM14, AM15: SN74LV4051A; TSSOP-16_4.4x5mm_P0.65mm
C1, C3, C5, C7, C9, C11, C13, C15, C17, C19, C21, C23, C25, C27, C29, C31, C33, C35, C37, C39, C41, C43, C45, C47, C49, C51, C53, C55, C57, C59, C61, C63, C65, C67, C69, C71, C73, C75, C77, C79, C81, C83, C85, C87, C89, C91, C93, C95, C97, C99, C101, C103, C105, C107, C109, C111, C113, C115, C117, C119, C121, C123, C125, C127, C129, C131, C133, C135, C137, C139, C140, C141, C142, C143, C144, C145, C146, C147, C148, C149, C150, C151, C161, C162, C163, C165, C167, C169, C171, C173, C175, C177, C179, C181, C183, C185, C187, C189, C191, C193, C195, C197, C199, C201, C203, C205, C207, C209, C211, C213, C215, C217, C219, C221, C223: 100n; C_0402_1005Metric
C2, C4, C6, C8, C10, C12, C14, C16, C18, C20, C22, C24, C26, C28, C30, C32, C34, C36, C38, C40, C42, C44, C46, C48, C50, C52, C54, C56, C58, C60, C62, C64, C66, C68, C70, C72, C74, C76, C78, C80, C82, C84, C86, C88, C90, C92, C94, C96, C98, C100, C102, C104, C106, C108, C110, C112, C114, C116, C118, C120, C122, C124, C126, C128, C130, C132, C134, C136, C138, C164, C166, C168, C170, C172, C174, C176, C178, C180, C182, C184, C186, C188, C190, C192, C194, C196, C198, C200, C202, C204, C206, C208, C210, C212, C214, C216, C218, C220, C222, C224: 4.7n; C_0402_1005Metric
D1, D2, D3: LED; LED_D3.0mm
HE1, HE2, HE3, HE4, HE5, HE6, HE7, HE8, HE9, HE10, HE11, HE12, HE13, HE14, HE15, HE16, HE17, HE18, HE19, HE20, HE21, HE22, HE23, HE24, HE25, HE26, HE27, HE28, HE29, HE30, HE31, HE32, HE33, HE34, HE35, HE36, HE37, HE38, HE39, HE40, HE41, HE42, HE43, HE44, HE45, HE46, HE47, HE48, HE49, HE50, HE51, HE52, HE53, HE54, HE55, HE56, HE57, HE58, HE59, HE60, HE61, HE62, HE63, HE64, HE65, HE66, HE67, HE68, HE69, HE70, HE71, HE72, HE73, HE74, HE75, HE76, HE77, HE78, HE79, HE80, HE81, HE82, HE83, HE84, HE85, HE86, HE87, HE88, HE89, HE90, HE91, HE92, HE93, HE94, HE95, HE96, HE97, HE98, HE99, HE100: MT9102ET; SOT-23-3
J1, J2: AudioJack3_Ground; Jack_3.5mm_PJ320E_Horizontal
J3: Screen Connector; PinHeader_1x04_P2.54mm_Vertical
MX1, MX2, MX3, MX4, MX5, MX6, MX7, MX8, MX9, MX10, MX11, MX12, MX13, MX15, MX16, MX17, MX18, MX19, MX20, MX21, MX22, MX23, MX24, MX25, MX26, MX27, MX28, MX29, MX31, MX32, MX33, MX34, MX35, MX36, MX37, MX38, MX39, MX40, MX41, MX42, MX45, MX46, MX47, MX48, MX49, MX50, MX51, MX52, MX53, MX54, MX55, MX56, MX57, MX58, MX60, MX61, MX62, MX63, MX64, MX65, MX66, MX67, MX68, MX69, MX71, MX72, MX73, MX74, MX75, MX76, MX77, MX78, MX79, MX80, MX81, MX82, MX83, MX84, MX85, MX86, MX87, MX88, MX89, MX90, MX91, MX92, MX93, MX94, MX95, MX96, MX97, MX98, MX99, MX100: 1U; MX-1U
MX14, MX30, MX43, MX59, MX70: 1.5U; MX-1.5U
MX44: 1u; MX-1U
R1, R2, R3: R_Small_US; R_Axial_DIN0204_L3.6mm_D1.6mm_P7.62mm_Horizontal
RV1, RV2, RV3, RV4, RV5, RV6, RV7, RV8, RV9, RV10, RV11, RV12: R_Potentiometer_Trim_US; Potentiometer_Alpha_RD901F-40-00D_Single_Vertical
U1: 74HC138; SOIC-16_3.9x9.9mm_P1.27mm

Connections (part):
+3.3VA: A1.38 (3V3_D), AM1.16 (VDD), AM2.16 (VDD), AM3.16 (VDD), AM4.16 (VDD), AM5.16 (VDD), AM6.16 (VDD), AM7.16 (VDD), AM8.16 (VDD), AM9.16 (VDD), AM10.16 (VDD), AM11.16 (VDD), AM12.16 (VDD), AM13.16 (VDD), AM14.16 (VDD), AM15.16 (VDD), C1.1, C3.1, C5.1, C7.1, C9.1, C11.1, C13.1, C15.1, C17.1, C19.1, C21.1, C23.1, C25.1, C27.1, C29.1, C31.1, C33.1, C35.1, C37.1, C39.1, C41.1, C43.1, C45.1, C47.1, C49.1, C51.1, C53.1, C55.1, C57.1, C59.1, C61.1, C63.1, C65.1, C67.1, C69.1, C71.1, C73.1, C75.1, C77.1, C79.1, C81.1, C83.1, C85.1, C87.1, C89.1, C91.1, C93.1, C95.1, C97.1, C99.1, C101.1, C103.1, C105.1, C107.1, C109.1, C111.1, C113.1, C115.1, C117.1, C119.1, C121.1, C123.1, C125.1, C127.1, C129.1, C131.1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
Audio_in_1: A1.16 (AUDIO_IN_1), J1.T
Audio_in_2: A1.17 (AUDIO_IN_2), J1.R1
Audio_out_1: A1.18 (AUDIO_OUT_1), J2.T
Audio_out_2: A1.19 (AUDIO_OUT_2), J2.R1
ENABLE_10: AM10.6 (Inh), U1.15 (~Y0)
ENABLE_11: AM11.6 (Inh), U1.14 (~Y1)
ENABLE_12: AM12.6 (Inh), U1.13 (~Y2)
ENABLE_13: AM13.6 (Inh), U1.12 (~Y3)
ENABLE_14: AM14.6 (Inh), U1.11 (~Y4)
ENABLE_15: AM15.6 (Inh), U1.10 (~Y5)
ENB_A: A1.5 (SD_DATA_0), U1.1 (A0)
ENB_B: A1.4 (SD_DATA_1), U1.2 (A1)
ENB_C: A1.3 (SD_DATA_2), U1.3 (A2)
GND: A1.20 (AGND), A1.40 (DGND), AM1.6 (Inh), AM1.7 (VEE), AM1.8 (VSS), AM2.6 (Inh), AM2.7 (VEE), AM2.8 (VSS), AM3.6 (Inh), AM3.7 (VEE), AM3.8 (VSS), AM4.6 (Inh), AM4.7 (VEE), AM4.8 (VSS), AM5.6 (Inh), AM5.7 (VEE), AM5.8 (VSS), AM6.6 (Inh), AM6.7 (VEE), AM6.8 (VSS), AM7.6 (Inh), AM7.7 (VEE), AM7.8 (VSS), AM8.6 (Inh), AM8.7 (VEE), AM8.8 (VSS), AM8.12 (X3), AM8.13 (X0), AM9.6 (Inh), AM9.7 (VEE), AM9.8 (VSS), AM10.7 (VEE), AM10.8 (VSS), AM10.12 (X3), AM11.7 (VEE), AM11.8 (VSS), AM11.12 (X3), AM12.7 (VEE), AM12.8 (VSS), AM13.7 (VEE), AM13.8 (VSS), AM14.7 (VEE), AM14.8 (VSS), AM15.7 (VEE), AM15.8 (VSS), AM15.12 (X3), AM15.13 (X0), AM15.14 (X1), AM15.15 (X2), C1.2, C2.2, C3.2, C4.2, C5.2, C6.2, C7.2, C8.2, C9.2, C10.2, C11.2, C12.2, C13.2, C14.2, C15.2, C16.2, C17.2, C18.2, C19.2, C20.2, C21.2, C22.2, C23.2, C24.2, C25.2, C26.2, C27.2, C28.2, C29.2, C30.2, C31.2, C32.2, C33.2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
HE1: AM1.1 (X4), C2.1, HE1.2 (OUT)
HE2: AM1.2 (X6), C4.1, HE2.2 (OUT)
HE3: AM1.4 (X7), C6.1, HE3.2 (OUT)
HE4: AM1.5 (X5), C8.1, HE4.2 (OUT)
HE5: AM1.15 (X2), C10.1, HE5.2 (OUT)
HE6: AM1.14 (X1), C12.1, HE6.2 (OUT)
HE7: AM1.13 (X0), C14.1, HE7.2 (OUT)
HE8: AM1.12 (X3), C16.1, HE8.2 (OUT)
HE9: AM2.1 (X4), C18.1, HE9.2 (OUT)
HE10: AM2.2 (X6), C20.1, HE10.2 (OUT)
HE11: AM2.4 (X7), C22.1, HE11.2 (OUT)
HE12: AM2.5 (X5), C24.1, HE12.2 (OUT)
HE13: AM2.15 (X2), C26.1, HE13.2 (OUT)
HE14: AM2.14 (X1), C28.1, HE14.2 (OUT)
HE15: AM3.1 (X4), C30.1, HE15.2 (OUT)
HE16: AM3.2 (X6), C32.1, HE16.2 (OUT)
HE17: AM3.4 (X7), C34.1, HE17.2 (OUT)
HE18: AM3.5 (X5), C36.1, HE18.2 (OUT)
HE19: AM3.15 (X2), C38.1, HE19.2 (OUT)
HE20: AM3.14 (X1), C40.1, HE20.2 (OUT)
HE21: AM3.13 (X0), C42.1, HE21.2 (OUT)
HE22: AM3.12 (X3), C44.1, HE22.2 (OUT)
HE23: AM4.1 (X4), C46.1, HE23.2 (OUT)
HE24: AM4.2 (X6), C48.1, HE24.2 (OUT)
HE25: AM4.4 (X7), C50.1, HE25.2 (OUT)
HE26: AM4.5 (X5), C52.1, HE26.2 (OUT)
HE27: AM4.15 (X2), C54.1, HE27.2 (OUT)
HE28: AM2.12 (X3), C56.1, HE28.2 (OUT)
HE29: AM2.13 (X0), C58.1, HE29.2 (OUT)
HE30: AM5.1 (X4), C60.1, HE30.2 (OUT)
HE31: AM5.2 (X6), C62.1, HE31.2 (OUT)
HE32: AM5.4 (X7), C64.1, HE32.2 (OUT)
HE33: AM5.5 (X5), C66.1, HE33.2 (OUT)
HE34: AM5.15 (X2), C68.1, HE34.2 (OUT)
HE35: AM5.14 (X1), C70.1, HE35.2 (OUT)
HE36: AM5.13 (X0), C72.1, HE36.2 (OUT)
HE37: AM5.12 (X3), C74.1, HE37.2 (OUT)
HE38: AM6.1 (X4), C76.1, HE38.2 (OUT)
HE39: AM6.2 (X6), C78.1, HE39.2 (OUT)
HE40: AM6.4 (X7), C80.1, HE40.2 (OUT)
HE41: AM4.14 (X1), C82.1, HE41.2 (OUT)
HE42: AM4.13 (X0), C84.1, HE42.2 (OUT)
HE43: AM4.12 (X3), C86.1, HE43.2 (OUT)
HE44: AM7.1 (X4), C88.1, HE44.2 (OUT)
HE45: AM7.2 (X6), C90.1, HE45.2 (OUT)
HE46: AM7.4 (X7), C92.1, HE46.2 (OUT)
HE47: AM7.5 (X5), C94.1, HE47.2 (OUT)
HE48: AM7.15 (X2), C96.1, HE48.2 (OUT)
HE49: AM7.14 (X1), C98.1, HE49.2 (OUT)
HE50: AM7.13 (X0), C100.1, HE50.2 (OUT)
HE51: AM7.12 (X3), C102.1, HE51.2 (OUT)
HE52: AM8.1 (X4), C104.1, HE52.2 (OUT)
HE53: AM8.2 (X6), C106.1, HE53.2 (OUT)
HE54: AM6.5 (X5), C108.1, HE54.2 (OUT)
HE55: AM6.15 (X2), C110.1, HE55.2 (OUT)
HE56: AM6.14 (X1), C112.1, HE56.2 (OUT)
HE57: AM6.13 (X0), C114.1, HE57.2 (OUT)
HE58: AM6.12 (X3), C116.1, HE58.2 (OUT)
HE59: AM9.1 (X4), C118.1, HE59.2 (OUT)
HE60: AM9.2 (X6), C120.1, HE60.2 (OUT)
HE61: AM9.4 (X7), C122.1, HE61.2 (OUT)
HE62: AM9.5 (X5), C124.1, HE62.2 (OUT)
HE63: AM9.15 (X2), C126.1, HE63.2 (OUT)
HE64: AM9.14 (X1), C128.1, HE64.2 (OUT)
HE65: AM9.13 (X0), C130.1, HE65.2 (OUT)
HE66: AM9.12 (X3), C132.1, HE66.2 (OUT)
HE67: AM8.4 (X7), C134.1, HE67.2 (OUT)
HE68: AM8.5 (X5), C136.1, HE68.2 (OUT)
HE69: AM8.15 (X2), C138.1, HE69.2 (OUT)
HE70: AM8.14 (X1), C164.1, HE70.2 (OUT)
HE71: AM10.1 (X4), C166.1, HE71.2 (OUT)
HE72: AM10.2 (X6), C168.1, HE72.2 (OUT)
HE73: AM10.4 (X7), C170.1, HE73.2 (OUT)
HE74: AM11.1 (X4), C172.1, HE74.2 (OUT)
HE75: AM11.2 (X6), C174.1, HE75.2 (OUT)
HE76: AM11.4 (X7), C176.1, HE76.2 (OUT)
HE77: AM11.5 (X5), C178.1, HE77.2 (OUT)
HE78: AM11.15 (X2), C180.1, HE78.2 (OUT)
HE79: AM11.14 (X1), C182.1, HE79.2 (OUT)
HE80: AM11.13 (X0), C184.1, HE80.2 (OUT)
HE81: AM10.5 (X5), C186.1, HE81.2 (OUT)
HE82: AM10.15 (X2), C188.1, HE82.2 (OUT)
HE83: AM10.14 (X1), C190.1, HE83.2 (OUT)
HE84: AM10.13 (X0), C192.1, HE84.2 (OUT)
HE85: AM12.1 (X4), C194.1, HE85.2 (OUT)
HE86: AM12.2 (X6), C196.1, HE86.2 (OUT)
HE87: AM12.4 (X7), C198.1, HE87.2 (OUT)
HE88: AM12.5 (X5), C200.1, HE88.2 (OUT)
HE89: AM12.15 (X2), C202.1, HE89.2 (OUT)
HE90: AM12.14 (X1), C204.1, HE90.2 (OUT)
HE91: AM12.13 (X0), C206.1, HE91.2 (OUT)
HE92: AM12.12 (X3), C208.1, HE92.2 (OUT)
HE93: AM13.1 (X4), C210.1, HE93.2 (OUT)
HE94: AM13.2 (X6), C212.1, HE94.2 (OUT)
HE95: AM13.4 (X7), C214.1, HE95.2 (OUT)
HE96: AM13.5 (X5), C216.1, HE96.2 (OUT)
HE97: AM13.15 (X2), C218.1, HE97.2 (OUT)
HE98: AM13.14 (X1), C220.1, HE98.2 (OUT)
HE99: AM13.13 (X0), C222.1, HE99.2 (OUT)
HE100: AM13.12 (X3), C224.1, HE100.2 (OUT)
MUX_OUT_1: A1.22 (ADC_0), AM1.3 (X)
MUX_OUT_2: A1.23 (ADC_1), AM2.3 (X)
MUX_OUT_3: A1.24 (ADC_2), AM3.3 (X)
MUX_OUT_4: A1.25 (ADC_3), AM4.3 (X)
MUX_OUT_5: A1.26 (ADC_4), AM5.3 (X)
MUX_OUT_6: A1.27 (ADC_5), AM6.3 (X)
MUX_OUT_7: A1.28 (ADC_6), AM7.3 (X)
MUX_OUT_8: A1.29 (DAC_OUT2), AM8.3 (X)
MUX_OUT_9: A1.30 (DAC_OUT1), AM9.3 (X)
MUX_OUT_10: A1.31 (SAI2_MCLK), AM10.3 (X), AM11.3 (X)
MUX_OUT_12: A1.32 (SAI2_SD_B), AM12.3 (X), AM13.3 (X)
MUX_OUT_14: A1.33 (SAI2_SD_A), AM14.3 (X), AM15.3 (X)
MUX_SELECT_0: A1.8 (SPI1_CS), AM1.11 (A), AM2.11 (A), AM3.11 (A), AM4.11 (A), AM5.11 (A), AM6.11 (A), AM7.11 (A), AM8.11 (A), AM9.11 (A), AM10.11 (A), AM11.11 (A), AM12.11 (A), AM13.11 (A), AM14.11 (A), AM15.11 (A)
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

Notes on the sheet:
AM9
AM6
AM12
AM7
AM14
AM8
AM1
AM15
AM3
AM2
AM11
AM5
AM10
AM13
AM4
Switches

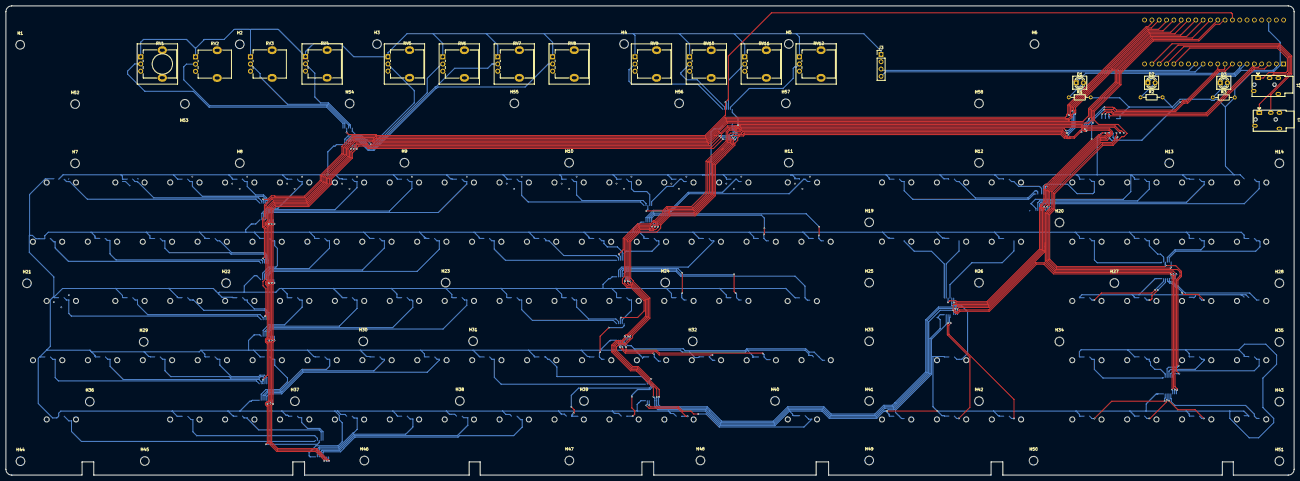
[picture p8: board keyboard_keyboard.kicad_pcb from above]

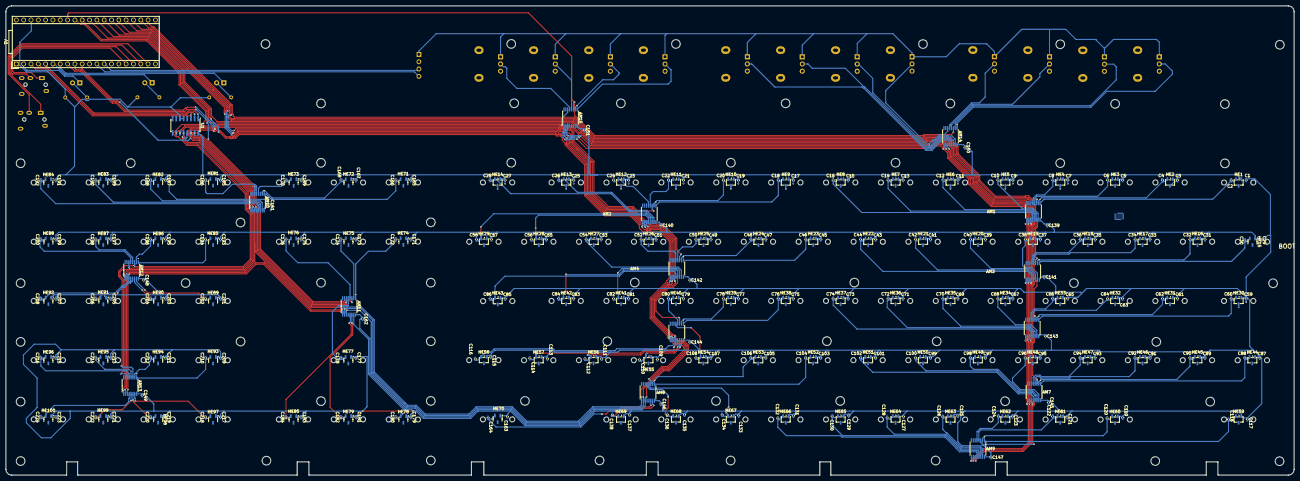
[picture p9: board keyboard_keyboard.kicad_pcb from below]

Board: 2 copper layers, 447.0 x 162.8 mm, 507 parts (332 on the bottom side), 150 nets.

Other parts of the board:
H1, H2, H3, H4, H5, H6, H7, H8, H9, H10, H11, H12, H13, H14, H19, H20, H21, H22, H23, H24, H25, H26, H27, H28, H29, H30, H31, H32, H33, H34, H35, H36, H37, H38, H39, H40, H41, H42, H43, H44, H45, H46, H47, H48, H49, H50, H51, H52, H53, H54, H55, H56, H57, H58: MountingHole; MountingHole_3mm

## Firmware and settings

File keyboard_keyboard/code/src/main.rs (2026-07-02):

//! hall_effect_keyboard — Daisy Seed MIDI keyboard firmware
//! MIDI out over USART1 at 31250 baud. See HARDWARE.md for full pin mapping.

#![no_main]
#![no_std]

use panic_rtt_target as _;

mod constants;
mod display;
mod hardware;
mod midi;
mod settings;
mod switch;
mod types;

#[rtic::app(
    device = stm32h7xx_hal::stm32,
    peripherals = true,
    dispatchers = [DMA1_STR2, DMA1_STR3, DMA1_STR4, DMA1_STR5, DMA1_STR6]
)]
mod app {
    use crate::constants::*;
    use crate::hardware::{
        i2c_bus_recovery, read_all_adcs, set_decoder, set_mux_channel, AdcPins, MuxRaw,
    };
    use crate::midi::MidiSender;
    use crate::settings::{Settings, NUM_SETTINGS_ITEMS};
    use crate::switch::{ChannelFilter, SwitchEvent, SwitchState};
    use crate::types::{DisplayState, LastEvent, LcdDisplay};

    use libdaisy::gpio::*;
    use libdaisy::logger;
    use libdaisy::{audio, system};
    use stm32h7xx_hal::time::MilliSeconds;

    use libdaisy::hal::{
        adc::{self, Adc, AdcSampleTime, Resolution},
        gpio::{Analog, Output, PushPull},
        prelude::*,
        serial::{config::Config as SerialConfig, Rx, SerialExt},
        stm32,
        time::U32Ext,
        timer,
    };
    use log::{info, warn};

    use fugit::RateExtU32;
    use ssd1306::{prelude::*, I2CDisplayInterface, Ssd1306};
    use stm32h7xx_hal::i2c::I2cExt;

    // T_1 (8.5 ADC cycles) — sufficient for HE sensor push-pull outputs.
    // T_16 was too slow for 9 muxes within a 1 ms TIM2 period.
    const ADC_SAMPLE_TIME: AdcSampleTime = AdcSampleTime::T_1;
    const ADC_RESOLUTION: Resolution = Resolution::TwelveBit;

    // ── Shared resources ──────────────────────────────────────────────────────
    #[shared]
    struct Shared {
        tick_ms: u32,
        switch_states: [SwitchState; NUM_SWITCHES],
        baselines: [u16; NUM_SWITCHES],
        event_queue: heapless::spsc::Queue<(usize, SwitchEvent), 64>,
        midi_tx_flag: bool,
        display_state: DisplayState,
        splash_done: bool,
        settings: Settings,
        settings_active: bool,
        settings_selected: usize,
        recalibrate_pending: bool,
    }

    // ── Local resources ───────────────────────────────────────────────────────
    #[local]
    struct Local {
        audio: audio::Audio,
        adc: Adc<stm32::ADC1, adc::Enabled>,
        adc_pins: AdcPins,
        enb_a: Daisy4<Output<PushPull>>, // U1 A0 (ENB_A)
        enb_b: Daisy3<Output<PushPull>>, // U1 A1 (ENB_B)
        enb_c: Daisy2<Output<PushPull>>, // U1 A2 (ENB_C)
        adc_pin_a9: Daisy24<Analog>,     // AM10+AM11 shared
        adc_pin_a10: Daisy25<Analog>,    // AM12+AM13 shared
        // Pad 33 (D26) has no ADC — wire pad 33 → pad 35 on Daisy Seed.
        adc_pin_a11: Daisy28<Analog>, // AM14+AM15 pots via pad 35 (A11)
        pot_last_cc: [u8; NUM_POTS],
        s0: Daisy7<Output<PushPull>>,   // MUX_SELECT_0
        s1: Daisy8<Output<PushPull>>,   // MUX_SELECT_1
        s2: Daisy9<Output<PushPull>>,   // MUX_SELECT_2
        led1: Daisy6<Output<PushPull>>, // active-low — MIDI TX flash
        led2: Daisy5<Output<PushPull>>, // active-low — MIDI RX flash
        led3: Daisy1<Output<PushPull>>, // active-low — heartbeat
        timer2: timer::Timer<stm32::TIM2>,
        mux_raw: MuxRaw,
        midi_sender: MidiSender,
        midi_rx: Rx<stm32::USART1>,
        filters: [ChannelFilter; NUM_SWITCHES],
        dynamic_baselines: [u16; NUM_SWITCHES],
        last_pitch_bend: u16,
        last_vibrato_cc: u8,
        led1_off_at: u32,
        led2_off_at: u32,
        display: Option<LcdDisplay>,
    }

    // ── init ──────────────────────────────────────────────────────────────────
    #[init]
    fn init(ctx: init::Context) -> (Shared, Local, init::Monotonics) {
        logger::init();

        let mut core = ctx.core;
        let device = ctx.device;

        let ccdr = system::System::init_clocks(device.PWR, device.RCC, &device.SYSCFG);
        let mut system = libdaisy::system_init!(core, device, ccdr, BLOCK_SIZE);

        let mut s0 = system
            .gpio
            .daisy7
            .take()
            .expect("daisy7")
            .into_push_pull_output();
        let mut s1 = system
            .gpio
            .daisy8
            .take()
            .expect("daisy8")
            .into_push_pull_output();
        let mut s2 = system
            .gpio
            .daisy9
            .take()
            .expect("daisy9")
            .into_push_pull_output();

        let mut adc_pins = (
            system.gpio.daisy15.take().expect("daisy15").into_analog(),
            system.gpio.daisy16.take().expect("daisy16").into_analog(),
            system.gpio.daisy17.take().expect("daisy17").into_analog(),
            system.gpio.daisy18.take().expect("daisy18").into_analog(),
            system.gpio.daisy19.take().expect("daisy19").into_analog(),
            system.gpio.daisy20.take().expect("daisy20").into_analog(),
            system.gpio.daisy21.take().expect("daisy21").into_analog(),
            system.gpio.daisy22.take().expect("daisy22").into_analog(),
            system.gpio.daisy23.take().expect("daisy23").into_analog(),
        );

        let mut enb_a = system
            .gpio
            .daisy4
            .take()
            .expect("daisy4")
            .into_push_pull_output();
        let mut enb_b = system
            .gpio
            .daisy3
            .take()
            .expect("daisy3")
            .into_push_pull_output();
        let mut enb_c = system
            .gpio
            .daisy2
            .take()
            .expect("daisy2")
            .into_push_pull_output();
        let mut adc_pin_a9 = system.gpio.daisy24.take().expect("daisy24").into_analog();
        let mut adc_pin_a10 = system.gpio.daisy25.take().expect("daisy25").into_analog();
        // Pad 35 (D28/A11) reads AM14+AM15. Requires bodge wire pad 33 → pad 35.
        let adc_pin_a11 = system.gpio.daisy28.take().expect("daisy28").into_analog();

        enb_a.set_low();
        enb_b.set_low();
        enb_c.set_low();

        let mut adc = system.adc1.enable();
        adc.set_resolution(ADC_RESOLUTION);
        adc.set_sample_time(ADC_SAMPLE_TIME);

        cortex_m::asm::delay(480 * 50_000);

        // ── Boot calibration ──────────────────────────────────────────────────
        let mut slot_sum = [[0u32; MUX_CHANNELS]; NUM_MUXES];
        let mut slot_count = [[0u32; MUX_CHANNELS]; NUM_MUXES];

        for ch in 0..MUX_CHANNELS {
            set_mux_channel(ch, &mut s0, &mut s1, &mut s2);
            cortex_m::asm::delay(480 * 200);
            for _ in 0..CALIBRATION_SAMPLES {
                let readings = read_all_adcs(&mut adc, &mut adc_pins);
                for mux in 0..NUM_ADC_PINS {
                    slot_sum[mux][ch] += readings[mux] as u32;
                    slot_count[mux][ch] += 1;
                }
                cortex_m::asm::delay(480 * 10);
                for decoder_idx in 0..4u8 {
                    set_decoder(decoder_idx, &mut enb_a, &mut enb_b, &mut enb_c);
                    cortex_m::asm::delay(480 * 5);
                    let mux_idx = 9 + decoder_idx as usize;
                    let r = if decoder_idx < 2 {
                        adc.read(&mut adc_pin_a9).unwrap_or(0u32) as u16
                    } else {
                        adc.read(&mut adc_pin_a10).unwrap_or(0u32) as u16
                    };
                    slot_sum[mux_idx][ch] += r as u32;
                    slot_count[mux_idx][ch] += 1;
                }
            }
        }

        let mut baselines = [0u16; NUM_SWITCHES];
        let mut filters = [ChannelFilter::new(); NUM_SWITCHES];
        for (switch_idx, &(mux, ch)) in SWITCH_MAP.iter().enumerate() {
            let avg = slot_sum[mux as usize][ch as usize]
                .checked_div(slot_count[mux as usize][ch as usize])
                .unwrap_or(0) as u16;
            baselines[switch_idx] = avg;
            filters[switch_idx].prime(avg);
            if DIAG_LOGGING {
                info!(
                    "baseline switch={} mux={} ch={} val={}",
                    switch_idx, mux, ch, avg
                );
            }
        }

        // ── MIDI UART ─────────────────────────────────────────────────────────
        let midi_tx_pin = system
            .gpio
            .daisy13
            .take()
            .expect("daisy13")
            .into_alternate::<7>();
        let midi_rx_pin = system
            .gpio
            .daisy14
            .take()
            .expect("daisy14")
            .into_alternate::<7>();
        let midi_serial = device
            .USART1
            .serial(
                (midi_tx_pin, midi_rx_pin),
                SerialConfig {
                    baudrate: 31_250_u32.bps(),
                    ..SerialConfig::default()
                },
                ccdr.peripheral.USART1,
                &ccdr.clocks,
            )
            .unwrap();
        let (midi_tx, midi_rx) = midi_serial.split();
        let midi_sender = MidiSender::new(midi_tx, 0);

        // ── Timer2 @ 1 kHz ────────────────────────────────────────────────────
        let mut timer2 = stm32h7xx_hal::timer::TimerExt::timer(
            device.TIM2,
            MilliSeconds::from_ticks(1).into_rate(),
            ccdr.peripheral.TIM2,
            &ccdr.clocks,
        );
        timer2.listen(timer::Event::TimeOut);

        let mut led1 = system
            .gpio
            .daisy6
            .take()
            .expect("daisy6")
            .into_push_pull_output();
        let mut led2 = system
            .gpio
            .daisy5
            .take()
            .expect("daisy5")
            .into_push_pull_output();
        let mut led3 = system
            .gpio
            .daisy1
            .take()
            .expect("daisy1")
            .into_push_pull_output();
        led1.set_high();
        led2.set_high();
        led3.set_high();

        // ── I2C + SSD1306 ─────────────────────────────────────────────────────
        let mut scl = system
            .gpio
            .daisy11
            .take()
            .expect("daisy11")
            .into_push_pull_output();
        let mut sda = system
            .gpio
            .daisy12
            .take()
            .expect("daisy12")
            .into_push_pull_output();
        i2c_bus_recovery(&mut scl, &mut sda);
        let scl = scl
            .into_alternate::<4>()
            .internal_pull_up(true)
            .set_open_drain();
        let sda = sda
            .into_alternate::<4>()
            .internal_pull_up(true)
            .set_open_drain();
        let i2c = device.I2C1.i2c(
            (scl, sda),
            100_u32.kHz(),
            ccdr.peripheral.I2C1,
            &ccdr.clocks,
        );
        let display = Some(
            Ssd1306::new(
                I2CDisplayInterface::new_custom_address(i2c, 0x3C),
                DisplaySize128x32,
                DisplayRotation::Rotate0,
            )
            .into_buffered_graphics_mode(),
        );
        display_update::spawn().ok();

        set_mux_channel(0, &mut s0, &mut s1, &mut s2);
        info!(
            "keyboard_keyboard ready: {} switches, {} muxes",
            NUM_SWITCHES, NUM_MUXES
        );

        (
            Shared {
                tick_ms: 0,
                switch_states: [SwitchState::new(); NUM_SWITCHES],
                baselines,
                event_queue: heapless::spsc::Queue::new(),
                midi_tx_flag: false,
                display_state: DisplayState::new(),
                splash_done: false,
                settings: Settings::default(),
                settings_active: false,
                settings_selected: 0,
                recalibrate_pending: false,
            },
            Local {
                audio: system.audio,
                adc,
                adc_pins,
                enb_a,
                enb_b,
                enb_c,
                adc_pin_a9,
                adc_pin_a10,
                adc_pin_a11,
                pot_last_cc: [255u8; NUM_POTS],
                s0,
                s1,
                s2,
                led1,
                led2,
                led3,
                timer2,
                mux_raw: [[0u16; MUX_CHANNELS]; NUM_MUXES],
                midi_sender,
                midi_rx,
                filters,
                dynamic_baselines: baselines,
                last_pitch_bend: 0x2000,
                last_vibrato_cc: 0,
                led1_off_at: 0,
                led2_off_at: 0,
                display,
            },
            init::Monotonics(),
        )
    }

    #[idle]
    fn idle(_ctx: idle::Context) -> ! {
        loop {
            cortex_m::asm::nop();
        }
    }

    // Priority 1 — below process_events so a slow display never blocks key events.
    // First spawn: init hardware + show splash. Subsequent spawns: redraw.
    #[task(
        local  = [display, initialized: bool = false],
        shared = [display_state, settings, settings_active, settings_selected],
        priority = 1,
        capacity = 2
    )]
    fn display_update(mut ctx: display_update::Context) {
        let Some(disp) = ctx.local.display.as_mut() else {
            return;
        };
        if !*ctx.local.initialized {
            match disp.init() {
                Ok(()) => {
                    *ctx.local.initialized = true;
                    crate::display::draw_splash(disp);
                    info!("display ok");
                }
                Err(_) => warn!("display not found"),
            }
            return;
        }

        let state = ctx.shared.display_state.lock(|s| *s);
        if state.recalibrating {
            crate::display::draw_recalibrating(disp);
            return;
        }

        let active = ctx.shared.settings_active.lock(|a| *a);
        if active {
            let selected = ctx.shared.settings_selected.lock(|s| *s);
            let settings = ctx.shared.settings.lock(|s| *s);
            crate::display::draw_settings(disp, selected, &settings);
        } else {
            crate::display::draw_main(disp, &state);
        }
    }

    #[task(binds = DMA1_STR1, priority = 8, local = [audio])]
    fn audio_handler(ctx: audio_handler::Context) {
        ctx.local.audio.for_each(|left, right| (left, right));
    }

    // ── 1 kHz scan loop ───────────────────────────────────────────────────────
    #[task(
        binds = TIM2,
        local  = [timer2, adc, adc_pins, enb_a, enb_b, enb_c, adc_pin_a9, adc_pin_a10,
                  adc_pin_a11, pot_last_cc, s0, s1, s2, mux_raw, filters, dynamic_baselines,
                  last_pitch_bend, last_vibrato_cc, led1, led2, led3, midi_rx,
                  led1_off_at, led2_off_at,
                  recalibrate_show_until: u32 = 0,
                  recalibrate_flashing: bool = false],
        shared = [tick_ms, switch_states, baselines, event_queue, midi_tx_flag, splash_done,
                  settings_active, recalibrate_pending, display_state],
        priority = 15
    )]
    fn timer_handler(mut ctx: timer_handler::Context) {
        ctx.local.timer2.clear_irq();

        let now = ctx.shared.tick_ms.lock(|t| {
            *t = t.wrapping_add(1);
            *t
        });

        if now % 2000 == 0 {
            info!("tick={}", now);
        }

        if now == SPLASH_DURATION_MS {
            ctx.shared.splash_done.lock(|d| *d = true);
            display_update::spawn().ok();
        }

        // Anchor for drift clamping — the last boot/recalibration snapshot, never
        // touched by per-tick tracking.
        let anchor_baselines = ctx.shared.baselines.lock(|b| *b);
        let settings_active = ctx.shared.settings_active.lock(|a| *a);
        let mut pending: heapless::Vec<(usize, SwitchEvent), 32> = heapless::Vec::new();

        // ── ADC scan ──────────────────────────────────────────────────────────
        for ch in 0..MUX_CHANNELS {
            set_mux_channel(ch, ctx.local.s0, ctx.local.s1, ctx.local.s2);
            cortex_m::asm::delay(480 * 10);
            let readings = read_all_adcs(ctx.local.adc, ctx.local.adc_pins);
            for (mux, &val) in readings.iter().enumerate() {
                ctx.local.mux_raw[mux][ch] = val;
            }
            for decoder_idx in 0..4u8 {
                set_decoder(
                    decoder_idx,
                    ctx.local.enb_a,
                    ctx.local.enb_b,
                    ctx.local.enb_c,
                );
                cortex_m::asm::delay(480 * 5);
                let mux_idx = 9 + decoder_idx as usize;
                ctx.local.mux_raw[mux_idx][ch] = if decoder_idx < 2 {
                    ctx.local.adc.read(ctx.local.adc_pin_a9).unwrap_or(0u32) as u16
                } else {
                    ctx.local.adc.read(ctx.local.adc_pin_a10).unwrap_or(0u32) as u16
                };
            }
        }

        // ── Switch state machine ───────────────────────────────────────────────
        let mut pb_filt_down = ctx.local.dynamic_baselines[PITCH_BEND_DOWN];
        let mut pb_filt_up = ctx.local.dynamic_baselines[PITCH_BEND_UP];
        let mut vib_filt_a = ctx.local.dynamic_baselines[VIBRATO_A];
        let mut vib_filt_b = ctx.local.dynamic_baselines[VIBRATO_B];

        ctx.shared.switch_states.lock(|states| {
            for (switch_idx, &(mux, ch)) in SWITCH_MAP.iter().enumerate() {
                let raw = ctx.local.mux_raw[mux as usize][ch as usize];
                let filtered = ctx.local.filters[switch_idx].feed(raw);

                // When settings is open the four arrow keys become digital plunger switches;
                let is_analog = switch_idx == PITCH_BEND_DOWN
                    || switch_idx == PITCH_BEND_UP
                    || switch_idx == VIBRATO_A
                    || switch_idx == VIBRATO_B;

                if is_analog && !settings_active {
                    if switch_idx == PITCH_BEND_DOWN {
                        pb_filt_down = filtered;
                    } else if switch_idx == PITCH_BEND_UP {
                        pb_filt_up = filtered;
                    } else if switch_idx == VIBRATO_A {
                        vib_filt_a = filtered;
                    } else {
                        vib_filt_b = filtered;
                    }
                } else if let Some(event) = states[switch_idx].update(
                    filtered,
                    ctx.local.dynamic_baselines[switch_idx],
                    now,
                    switch_idx,
                ) {
                    pending.push((switch_idx, event)).ok();
                }

                // Idle-state baseline tracking: absorb slow drift on floating /
                // unconnected inputs without ever corrupting an active-press baseline.
                let at_rest = if is_analog && !settings_active {
                    filtered.abs_diff(ctx.local.dynamic_baselines[switch_idx]) < RELEASE_DELTA
                } else {
                    states[switch_idx].is_idle()
                        && filtered.abs_diff(ctx.local.dynamic_baselines[switch_idx])
                            < RELEASE_DELTA
                };
                if at_rest {
                    let db = &mut ctx.local.dynamic_baselines[switch_idx];
                    let tracked = ((*db as u32 * (BASELINE_TRACKING_ALPHA - 1) + filtered as u32)
                        / BASELINE_TRACKING_ALPHA) as u16;
                    // Clamp to the boot/recalibration anchor so sustained crosstalk from a
                    // held chord can never drift a neighboring baseline far enough to cause
                    // a phantom trigger once the chord releases.
                    let anchor = anchor_baselines[switch_idx];
                    *db = tracked.clamp(
                        anchor.saturating_sub(BASELINE_DRIFT_MAX),
                        anchor.saturating_add(BASELINE_DRIFT_MAX),
                    );
                }
            }
        });

        // ── Pitch bend (rate-limited, only when settings is closed) ───────────
        if !settings_active && now % PITCH_BEND_INTERVAL_MS == 0 {
            let delta_down = pb_filt_down.abs_diff(ctx.local.dynamic_baselines[PITCH_BEND_DOWN]);
            let delta_up = pb_filt_up.abs_diff(ctx.local.dynamic_baselines[PITCH_BEND_UP]);
            let pb_value = if delta_down < RELEASE_DELTA && delta_up < RELEASE_DELTA {
                0x2000u16
            } else {
                let bend_down = (delta_down.min(PITCH_BEND_MAX_DELTA) as u32 * 0x2000
                    / PITCH_BEND_MAX_DELTA as u32) as u16;
                let bend_up = (delta_up.min(PITCH_BEND_MAX_DELTA) as u32 * 0x1FFF
                    / PITCH_BEND_MAX_DELTA as u32) as u16;
                (0x2000u16.saturating_sub(bend_down))
                    .saturating_add(bend_up)
                    .min(0x3FFF)
            };
            if pb_value.abs_diff(*ctx.local.last_pitch_bend) >= PITCH_BEND_HYSTERESIS {
                *ctx.local.last_pitch_bend = pb_value;
                pending
                    .push((0, SwitchEvent::PitchBend { value: pb_value }))
                    .ok();
            }
        }
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

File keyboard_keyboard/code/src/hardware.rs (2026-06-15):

use crate::constants::{MUX_CHANNELS, NUM_ADC_PINS, NUM_MUXES};

use libdaisy::gpio::*;
use libdaisy::hal::{
    adc::{self, Adc},
    gpio::{Analog, Output, PushPull},
    prelude::*,
    stm32,
};

pub type AdcPins = (
    Daisy15<Analog>,
    Daisy16<Analog>,
    Daisy17<Analog>,
    Daisy18<Analog>,
    Daisy19<Analog>,
    Daisy20<Analog>,
    Daisy21<Analog>,
    Daisy22<Analog>,
    Daisy23<Analog>,
);

pub type MuxRaw = [[u16; MUX_CHANNELS]; NUM_MUXES];

/// Drive the three mux select lines to address channel `ch` (0–7).
#[inline(always)]
pub fn set_mux_channel(
    ch: usize,
    s0: &mut Daisy7<Output<PushPull>>,
    s1: &mut Daisy8<Output<PushPull>>,
    s2: &mut Daisy9<Output<PushPull>>,
) {
    if ch & 0b001 != 0 {
        s0.set_high()
    } else {
        s0.set_low()
    }
    if ch & 0b010 != 0 {
        s1.set_high()
    } else {
        s1.set_low()
    }
    if ch & 0b100 != 0 {
        s2.set_high()
    } else {
        s2.set_low()
    }
}

/// Select one of AM10–AM15 via the 74HC138 decoder.
/// idx: 0=AM10, 1=AM11, 2=AM12, 3=AM13, 4=AM14 (pots), 5=AM15 (pots).
#[inline(always)]
pub fn set_decoder(
    idx: u8,
    enb_a: &mut Daisy4<Output<PushPull>>,
    enb_b: &mut Daisy3<Output<PushPull>>,
    enb_c: &mut Daisy2<Output<PushPull>>,
) {
    if idx & 0b001 != 0 {
        enb_a.set_high()
    } else {
        enb_a.set_low()
    }
    if idx & 0b010 != 0 {
        enb_b.set_high()
    } else {
        enb_b.set_low()
    }
    // A2 bit: 0 = AM10–13 (switches), 1 = AM14–15 (pots)
    if idx & 0b100 != 0 {
        enb_c.set_high()
    } else {
        enb_c.set_low()
    }
}

/// Read all 9 ADC mux inputs in one shot.
#[inline(always)]
pub fn read_all_adcs(
    adc: &mut Adc<stm32::ADC1, adc::Enabled>,
    pins: &mut AdcPins,
) -> [u16; NUM_ADC_PINS] {
    let r = |res: Result<u32, _>| res.unwrap_or(0) as u16;
    [
        r(adc.read(&mut pins.0)),
        r(adc.read(&mut pins.1)),
        r(adc.read(&mut pins.2)),
        r(adc.read(&mut pins.3)),
        r(adc.read(&mut pins.4)),
        r(adc.read(&mut pins.5)),
        r(adc.read(&mut pins.6)),
        r(adc.read(&mut pins.7)),
        r(adc.read(&mut pins.8)),
    ]
}

/// Pulse SCL 9× as GPIO then send a STOP condition to release any I2C device
/// holding SDA low after a reset. Call this before handing the pins to the I2C
/// peripheral.
pub fn i2c_bus_recovery(scl: &mut Daisy11<Output<PushPull>>, sda: &mut Daisy12<Output<PushPull>>) {
    scl.set_high();
    sda.set_high();
    cortex_m::asm::delay(480 * 10);
    for _ in 0..9 {
        scl.set_low();
        cortex_m::asm::delay(480 * 5);
        scl.set_high();
        cortex_m::asm::delay(480 * 5);
    }
    // STOP condition: SDA rises while SCL is high
    scl.set_low();
    cortex_m::asm::delay(480 * 5);
    sda.set_low();
    cortex_m::asm::delay(480 * 5);
    scl.set_high();
    cortex_m::asm::delay(480 * 5);
    sda.set_high();
    cortex_m::asm::delay(480 * 10);
}

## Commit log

2026-02-19 wip pcb
    [keyboard_keyboard.kicad_pcb, keyboard_keyboard.kicad_sch]
2026-02-26 move things around
    [keyboard_keyboard.kicad_pcb]
2026-02-27 more routing
    [keyboard_keyboard.kicad_pcb, keyboard_keyboard.kicad_sch]
2026-03-06 more keys
    [keyboard_keyboard.kicad_pcb, keyboard_keyboard.kicad_sch]
2026-03-06 feat: place everything*
    [keyboard_keyboard.kicad_pcb, keyboard_keyboard.kicad_sch]
2026-03-06 add pins for screen
    [keyboard_keyboard.kicad_sch]
2026-03-21 update wires
    [keyboard_keyboard.kicad_pcb, keyboard_keyboard.kicad_sch]
2026-03-21 more routes
    [keyboard_keyboard.kicad_pcb]
2026-03-28 wire more stuff
    [keyboard_keyboard.kicad_pcb]
2026-03-29 add routes
    [keyboard_keyboard.kicad_sch]
2026-03-29 add zones and vias
    [keyboard_keyboard.kicad_sch]
2026-03-29 fix gnd
    [keyboard_keyboard.kicad_sch]
2026-03-29 prepare for fab
    [keyboard_keyboard-B_Cu.gbr, keyboard_keyboard-B_Mask.gbr, keyboard_keyboard-B_Paste.gbr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]
2026-04-25 note sure what do
    [keyboard_keyboard-B_Cu.gbr, keyboard_keyboard-B_Mask.gbr, keyboard_keyboard-B_Paste.gbr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]
2026-05-28 Add skills, hardware doc, and display/I2C support
    Add multiple agent skill specs and hardware documentation, and extend firmware with I2C/display and LED features. New files: several .agents SKILL.md entries (caveman, caveman-review, daisy-seed-rtic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
2026-05-28 wip: this doesn't work but theoretically should
    [main.rs]
2026-05-28 feat: layout groundwork for all 100 keys and potentiometers
2026-05-28 fix: mux enable pins wrong
    [keyboard_keyboard.kicad_sch]
2026-05-30 feat: wire pots
    [keyboard_keyboard.kicad_sch]
2026-06-06 Rename keys to switches and add drum pads
    Refactors key-centric code to a switch-centric model and adds drum-pad support.
    - Renamed NUM_KEYS/KEY_MAP/KEY_TO_NOTE/KeyState/KeyPhase/KeyEvent/etc. to NUM_SWITCHES/SWITCH_MAP/SWITCH_TO_NOTE/SwitchState/SwitchPhase/SwitchEvent and updated all usages accordingly.
    - Replaced the previous key-to-note generator with an explicit SWITCH_TO_NOTE array implementing a Wicki-Hayden layout; unused switches map to note 0 and are skipped.
    - Added drum pad configuration: DRUM_CHANNEL, DRUM_SWITCH_START and DRUM_NOTE array; process_events routes drum switches to the drum MIDI channel and maps them to the drum notes.
    - Updated baselines, filters, event_queue size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
    [main.rs]
2026-06-13 fix: resolve CI fmt and clippy failures
    Run cargo fmt to fix whitespace/line-length diffs; replace manual checked-division with checked_div to satisfy clippy::manual_checked_ops.
    [main.rs]
2026-06-13 Feat: pitch bend and vibrado (#14)
    * Add pitch-bend sensor support
    Introduce pitch-bend handling from two ADC sensors: add constants for sensor indices, max delta, hysteresis and rate limit. Add a PitchBend event variant and last_pitch_bend state, initialize it to center, and include it in the TIM2 task locals. Sample and filter the two bend sensors, compute a 14-bit combined pitch-bend value (center snap when idle), apply hysteresis and rate limiting, enqueue PitchBend events, and send MIDI pitch-bend messages when changes exceed the threshold. Also wire diagnostic logging for pitch-bend messages.
    * feat: vibrado
    * Update main.rs
    [main.rs]
2026-07-02 Feat settings (#17)
    * add settings
    * fmt more like fml
    * settings: program change and recalibration
    * format
    * oosp - turn back off logging
    * kill notes for prev cxchannel
    * Clamp baseline drift to prevent phantom triggers
    Sustained crosstalk from held chords can drift neighboring switch baselines far enough to cause phantom key triggers when the chord releases. This commit adds `BASELINE_DRIFT_MAX` to hard-cap how far tracked baselines may wander from their boot-calibrated anchor values. Tracked baselines are now clamped within ±40 ADC counts of the anchor, preventing drift-induced false triggers while still allowing fast adaptive tracking.
    ---------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
    [main.rs, switch.rs, types.rs]
2026-11-08 Reproduce keyboard scan stalls on the virtual Seed [skip ci]
    Actual unchanged-ELF paired experiments passed on both profiles, with host checks and recorded evidence. The continuous one-hour soak is implemented but NOT_RUN; thermal and power behavior are unmodeled.
2026-11-08 Fix keyboard scan stalls, burst event loss and decoder copper [skip ci]
    Locally verified actual-ELF timing, chord and overload recovery, Rust build/Clippy/format checks, and native KiCad repair/refill reports. Thermal validation, physical board rework and flashing remain hardware tasks; no flash device is connected.
2026-11-09 Improve Hall-key velocity timing with simulation evidence [skip ci]
    Soft and hard strokes can collapse to the same MIDI velocity: the old two-phase debounce imposes a minimum measured interval, then an 80 ms response maps most short intervals near maximum. In the controlled 600-count simulation, 2/4/8/16 ms full-travel strokes all emitted 124.
    Record interpolated threshold crossings before debounce with a separate two-sample velocity filter, retaining four-sample trigger smoothing and consecutive confirmation. Add a configurable three-anchor response and validated per-key endpoint calibration. Defaults keep the existing trigger thresholds; timing anchors are provisional pending real keyboar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
